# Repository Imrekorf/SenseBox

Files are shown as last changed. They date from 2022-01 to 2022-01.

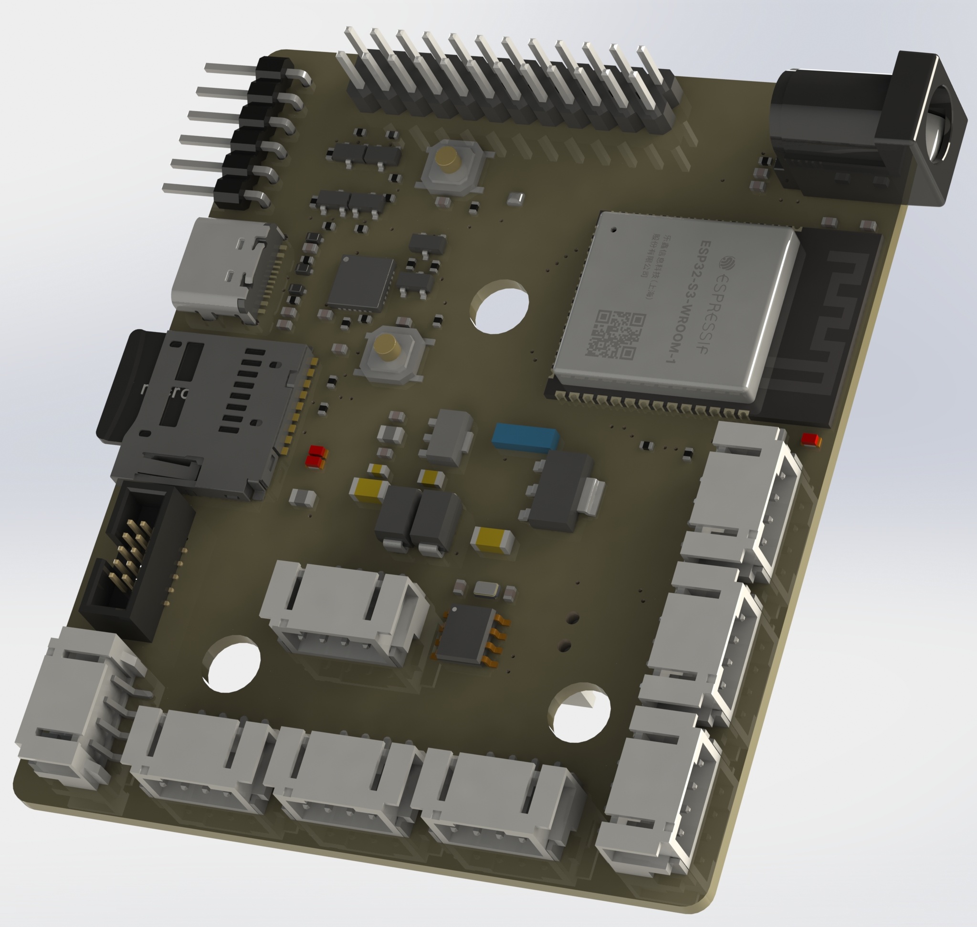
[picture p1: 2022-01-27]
Schematics/Eagle/Models/renderESP32.JPG

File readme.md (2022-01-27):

# Table of contents
- [Table of contents](#table-of-contents)
- [setup guide](#setup-guide)
- [Hardware setup guide](#hardware-setup-guide)
	- [Soldering list](#soldering-list)
	- [Managing the power source](#managing-the-power-source)
	- [Connecting the sensors](#connecting-the-sensors)
		- [Datasheets from the currently used sensors](#datasheets-from-the-currently-used-sensors)
		- [Schematics usage](#schematics-usage)
- [Programming the PCB](#programming-the-pcb)
- [Troubleshooting errors](#troubleshooting-errors)
	- [RTC](#rtc)
	- [SD](#sd)
	- [Sensor initialisation errors](#sensor-initialisation-errors)
- [Correct Installation check](#correct-installation-check)

# setup guide

1. Clone this github repo
2. Generate a MQTTSettings.dat file using the ArduinoConfig-Generator script.
3. Move generated MQTTSettings.dat to SD card's root folder.
4. Power the PCB.

# Hardware setup guide

## Soldering list
1. Solder the DC barreljack
2. Solder the BT1 Battery holder.[^1]
3. Solder the Laser dust sensor connector pins.[^1]
4. Solder the VR5V and VR5V jumpers.

[^1]: Currently the Laser Dust sensor connectors and Battery holder have not yet arrived so that sensor and battery holder can not be connected yet.

## Managing the power source
Depending on the circumstance you might want to power the PCB from the USB connection.<br>
To do this, **first**, you must make sure that VR5V and VR3V3 solder pads are not soldered. This can be identified by seeing 2 small pads on both the solder pads.<br>
Secondly you must solder the USB3V3 and USB5V to provide power to the board from the USB.<br>
If the DC barreljack is used you must **desolder** the USB3V3 and USB5V and then solder the VR3V3 and VR5V.<br>
<br>
To power the RTC you must either solder on the battery holder on the BT1 footprint. Or you can solder a wire from the VR3V3 or USB3V3, whichever is currently providing the 3V3 power, to the 3V3 pad of the Battery holder pads. See the board schematic included in the Schematics folder for more details.<br><br>

## Connecting the sensors
The sensors should be connected to the different JST headers provided on the board. To do this you need male `JST-PH 2.0 4 pin connectors`. 
These can be ordered from [vanallesenmeer.nl](https://www.vanallesenmeer.nl/JST-2.0-PH-4pin-set-recht-met-kabel-30cm) for €0.95.
These cables' other end can then be soldered to the sensors. Currently i2c compatible devices are wired as followed from left to right:
1. SCL : black
2. SDA : red
3. 3v3 : white
4. GND : yellow.

Other sensors' connection diagrams should be taken from the provided schematics.

### Datasheets from the currently used sensors
- [SCD30-datasheet](https://docs.rs-online.com/2d49/0900766b816b6f9d.pdf) & [SCD30-interface descriptor](https://docs.rs-online.com/ba78/0900766b816b6f9c.pdf)
- [Ambimate datasheet](https://docs.rs-online.com/6304/A700000006497831.pdf), [Product specifications](https://www.te.com/commerce/DocumentDelivery/DDEController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), [Application Specifications](https://www.te.com/commerce/DocumentDelivery/DDEController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), [customer drawings](https://eu.mouser.com/datasheet/2/418/7/ENG_CD_2314291_A2-2032749.pdf)
- [TSL2591](https://learn.adafruit.com/adafruit-tsl2591/downloads)
- [AS7262](https://learn.adafruit.com/adafruit-as7262-6-channel-visible-light-sensor/overview)
- [SM-UART-04L](https://www.farnell.com/datasheets/2756490.pdf)
- [MIX8410](https://wiki.seeedstudio.com/Grove-Gas_Sensor-O2-MIX8410/)
- [MAX4466](https://datasheets.maximintegrated.com/en/ds/MAX4465-MAX4469.pdf)
- [PCF8563](https://www.nxp.com/docs/en/data-sheet/PCF8563.pdf)

Any other datasheets needed are included in the EAGLE library. Check the description of the different components to find these datasheets.

### Schematics usage
The .sch and .brd file contain the electrical diagrams and PCB board layout respectively. The pdf contains a quick summary of the .sch file.
The .sch and .brd files can be loaded into the Autocad EAGLE software to make changes and view other information.
The .csv files contain JLCPCB part numbers and placements. These are used to order the right SMD components on the board.

# Programming the PCB
To program the ESP32 on the PCB, provide a power source, either through the USB or the barrel jack depending on the currently soldered connections.
Then load the code into the arduino ide by opening the .ino file. You then need to select the ESP32 dev module as your board in the Tools section.
If this is not already present follow the following [tutorial](https://randomnerdtutorials.com/installing-the-esp32-board-in-arduino-ide-windows-instructions/) to add support for these boards.
Select the correct port in the arduino ide and upload the code.
**important:** when the "connecting ...." prompt comes up, press and hold the RST and BOOT buttons, then release the RST button. if the prompt stops printing `.` or `-`'s then release the BOOT button.

# Troubleshooting errors
The most common errors in the serial output will be that either the RTC, SD or other sensors are not connected. Currently the program does not stop at these errors which could lead to a SYS_RST error message from the ESP32.
## RTC
If the RTC is not working there is either a short circuit on the i2c bus or the RTC does not have power. The RTC is the first module to be initialized in the system for logging purposes, so this has some major consequences when it's not working.

## SD
The most common SD card error is that it is not plugged in. Which can be solved by plugging in the SD card, or replugging the SD card and restarting the system when it was plugged in.
The provided SD card should be flashed with an FAT32 format to make sure the ESP32 can write to it.

## Sensor initialisation errors
If problems arise with the sensors not initializing it is likely due to bad wiring or not being connected at all.

# Correct Installation check
If the installation and connections are all correct you should see the following popping up in the serial monitor after a reset.

```
[14:39:31] [Info]: AmbiMate Firmware version 2.8
[14:39:32] [Info]: AS7262 initialized
[14:39:32] [Info]: SM_UART_4L found and initialized.
[14:39:32] [Info]: SCD30 initialized.
[14:39:32] [Info]: Found a TSL2591 sensor
[14:39:32] [Info]: TSL2591 bootup
------------------------------------
Gain:         25x (Medium)
Timing:       300 ms
------------------------------------

[14:39:33] [Info]: Connecting to WiFi .......
Connencted to wiFi with ip: 192.168.178.53
[14:39:38] [Info]: 
Starting connection to server...
[14:39:38] [Info]: The client SenseBox_test connects to the public mqtt broker
[54:39:40] [Info]: Mqtt broker connected
```

Followed by Info logs containing sensor data.
This data should also be partially tracable to the IoT platform.

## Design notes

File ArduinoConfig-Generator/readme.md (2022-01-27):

# ArduinoConfig-Generator
This script generates a dat file containing encrypted internet connection data.
The script can be expanded on by added variables to the WiFiSettings struct and adding a way to set it in the `getWifiConfig()` function.
If new variables are added, don't forget to also implement a formatting method on the ESP32 code. 
This should be done in the MQTTClient::getSettings() function.

# compiling

compile on an msys2 configured machine by using `make`
otherwise use `make -f MakefileWindows` aslong as you have a preconfigured g++ path.

# installing

After compiling copy the MQTTSettings.dat to the appointed path on the SD card. ( by default the root folder. )
The ESP32 will handle the decrypting.

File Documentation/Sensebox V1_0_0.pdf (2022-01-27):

## Sensebox

Generated by Doxygen 1.9.2

i

1 Module Index | 1
2 Hierarchical Index | 3
3 Class Index | 5
4 File Index | 7
5 Module Documentation | 9
6 Class Documentation | 15

Generated by Doxygen

ii

iii

iv

v

7 File Documentation | 65

vi

Index | 85

# Chapter 1

# Module Index

## 1.1 Modules

Here is a list of all modules:

### 2 Module Index

# Chapter 2

# Hierarchical Index

## 2.1 Class Hierarchy

This inheritance list is sorted roughly, but not completely, alphabetically:

__iW_Module | 15
Logger | 51
__W_AS726X | 19
__W_Ambimate | 17
__W_MAX4466 | 24
__W_MIX8410 | 26
__W_RTC | 28
__W_SCD30 | 30
__W_SD | 37
__W_SM_UART_4L | 43
__W_TSL2591 | | 45
AmbimateData | | 48
ColorSpectrum | | 50
iSingleton | | 51
Logger | 51
__W_AS726X | 19
__W_Ambimate | 17
__W_MAX4466 | 24
__W_MIX8410 | 26
__W_RTC | 28
__W_SCD30 | 30
__W_SD | 37
__W_SM_UART_4L | 43
__W_TSL2591 | | 45
RTC_DATE_TIME | | 57
SBox | | 58
SCD30_DATA | | 61
TSL2591_DATA | | 62

### 4 Hierarchical Index

# Chapter 3

# Class Index

## 3.1 Class List

Here are the classes, structs, unions and interfaces with brief descriptions:

__iW_Module
Interface for a hardware module hardware module should be implemented as a singleton to ensure that there won't be two processes accessing the same hardware at the same time Singleton

__W_Ambimate

__W_AS726X

__W_MAX4466

__W_MIX8410

__W_RTC

__W_SCD30

__W_SD

__W_SM_UART_4L

__W_TSL2591

AmbimateData

ColorSpectrum

iSingleton
Singleton template this doesn't actually implement anything, but this is more for keeping track if
a class is a singleton. Should assure that only one instance of the class can exist at a time | . . | 51
Logger
Logger singleton class. Logger is implemented as a Singleton to prevent two simultaneous logger

RTC_DATE_TIME

SBox

### 6 Class Index

SCD30_DATA

TSL2591_DATA

# Chapter 4

# File Index

## 4.1 File List

Here is a list of all documented files with brief descriptions:

src/Defines/Defines.h

src/Logger/Logger.h

src/Sbox/Sbox.h

src/Wrappers/__W_Module/__iW_Module.h

src/Wrappers/RTC/__W_RTC.h

src/Wrappers/SD/__W_SD.h

src/Wrappers/Sensors/Ambimate/__W_Ambimate.h

src/Wrappers/Sensors/AS7262/__W_AS726X.cpp

src/Wrappers/Sensors/DustSensor/__W_SMUART_4L.h

src/Wrappers/Sensors/MAX4466/__W_MAX4466.h

src/Wrappers/Sensors/MIX8410/__W_MIX8410.h

src/Wrappers/Sensors/SCD30/__W_SCD30.h

src/Wrappers/Sensors/TSL2591/__W_TSL2591.h

src/Wrappers/Singleton/Singleton.h

### 8 File Index

# Chapter 5

# Module Documentation

## 5.1 Global defines

Macros

- #define SenseBox_VERSION "0.0.1"

Version of the Sensebox software A change in the first version indicator is a major version change which might not be compatible with older major versions A change in the second version indicator is a minor version change which should be compatible with other of the same major versions A change in the third version indicator is a tweak version change, this will include mostly small bug fixes

- #define DEBUGLEVEL 3

Used by the source code to indicate what to debug to serial monitor.
- #define LOGLEVEL 3

Used by the source code to indicate what to log to the SD card.

### 5.1.1 Detailed Description

### 5.1.2 Macro Definition Documentation

### 5.1.2.1 DEBUGLEVEL

#define DEBUGLEVEL 3

Used by the source code to indicate what to debug to serial monitor.

Value | Description
0 | Print nothing to serial
1 | Print errors to serial
2 | Print errors and warnings to serial
3 | Print errors, warnings & info to serial
4 | Print errors, Warnings, info & data-dumps to serial

### 10 Module Documentation

### 5.1.2.2 LOGLEVEL

#define LOGLEVEL 3

Used by the source code to indicate what to log to the SD card.

Value | Description
0 | Log nothing
1 | Logs only errors
2 | Logs errors & warnings
3 | Logs errors, warnings & info
4 | Logs errors, warnings, info & data-dumps

## 5.2 Global Enumerations

Enumerations

- enum ERR_Type {
SUCCESS = 0 , READ_SUCCESS = 0 , ALREADY_INITIALIZED = 0 , ERROR = 1 , READ_ERROR = 1 , READ_FAIL = 1 , NOT_INITIALIZED , SD_NOT_INIT , MOD_INIT_ERR , RTC_BEGIN_ERR , SD_BEGIN_ERR , NO_SD_CARD , SD_CARDTYPE_NONE , SD_DIR_OPEN_FAIL , SD_NOT_A_DIR , SD_MKDIR_FAIL , SD_RMDIR_FAIL , SD_FILE_OPEN_FAIL , SD_WRITE_FAIL , SD_APP_FAIL , SD_RENAME_FAIL , SD_RM_FAIL , AMBI_I2C_INIT_ERR , AS726X_BEGIN_ERR , AS726X_DATA_NOT_READY , NO_LDS_SENSOR , SCD30_BEGIN_ERR , TSL_BEGIN_ERR }

List of function return errors.
- enum class LogLevel {
LogLevel::Error , LogLevel::Warning , LogLevel::Info , LogLevel::DataDump ,
LogLevel::__PREV }

Enum values that indicate the log level of the message.
- enum class LogType { LogType::SD = 0b01 , LogType::Serial = 0b10 , LogType::Serial_SD = 0b11 }

Enum values that indicate to which logging device should be logged.

### 5.2.1 Detailed Description

### 5.2.2 Enumeration Type Documentation

### 5.2.2.1 ERR_Type

enum ERR_Type

List of function return errors.

5.2 Global Enumerations | 11

Enumerator

SUCCESS | SUCCESS, No error occured.
READ_SUCCESS | READ_SUCCESS, A read operation was succesfull.
ALREADY_INITIALIZED | ALREADY_INITIALIZED, Module's init function was called multiple times.
ERROR | ERROR, generic error
READ_ERROR | READ_ERROR, A generic read error
READ_FAIL | READ_FAIL, A read operation failed.
NOT_INITIALIZED | NOT_INITIALIZED, Indicates that the module has not been initialized correctly.
SD_NOT_INIT | SD_NOT_INIT, indicates that the SD has not been properly initialized.
MOD_INIT_ERR | MOD_INIT_ERR, indicates that a module was not succesfully initialized.
RTC_BEGIN_ERR | RTC_BEGIN_ERR, indicates that the .begin() method has failed.
SD_BEGIN_ERR | SD_BEGIN_ERR, indicates that the .begin() method has failed.
NO_SD_CARD | NO_SD_CARD, indicates that no SD card was inserted.
SD_CARDTYPE_NONE | SD_CARDTYPE_NONE, indicates that the inserted SD card type is not supported.
SD_DIR_OPEN_FAIL | SD_DIR_OPEN_FAIL, failed to open given directory.
SD_NOT_A_DIR | SD_NOT_A_DIR, given directory does not exist
SD_MKDIR_FAIL | SD_MKDIR_FAIL, failed to create given directory
SD_RMDIR_FAIL | SD_RMDIR_FAIL, failed to remove given directory
SD_FILE_OPEN_FAIL | SD_FILE_OPEN_FAIL, failed to open given file
SD_WRITE_FAIL | SD_WRITE_FAIL, failed to write message to file
SD_APP_FAIL | SD_APP_FAIL, failed to append message to file
SD_RENAME_FAIL | SD_RENAME_FAIL, failed to rename file
SD_RM_FAIL | SD_RM_FAIL, failed to remove file
AMBI_I2C_INIT_ERR | AMBI_I2C_INIT_ERR, Aindicates that an I2C error occured in the init function.
AS726X_BEGIN_ERR | AS726X_BEGIN_ERR, indicates that the .begin() method has failed.
AS726X_DATA_NOT_READY | AS726X_DATA_NOT_READY, indicates that a ready was attempted but data was not yet ready
NO_LDS_SENSOR | NO_LDS_SENSOR, indicates that no LDS sensor was found.
SCD30_BEGIN_ERR | SCD30_BEGIN_ERR, indicates that the .begin() method has failed.
TSL_BEGIN_ERR | TSL_BEGIN_ERR, indicates that the .begin() method has failed.

### 5.2.2.2 LogLevel

enum class LogLevel [strong]

Enum values that indicate the log level of the message.

See also

LogType

Logger::print()

Logger::println()

Logger::write()

### 12 Module Documentation

Enumerator

Error | (0) Error level, This is used for when an error occures that can break the rest of the system.
Warning | (1) Warning level, This is used for when an error occures that does not have a signficiant impact on the system.
Info | (2) Info level, This is used for logging info or debugging info to the SD card.
DataDump | (3) DataDump, This is a special type of logging used for big blocks of data.
__PREV | () __PREV, default value for the logging functions, if this is passed to the function it will use the previous log level.

### 5.2.2.3 LogType

enum class LogType [strong]

Enum values that indicate to which logging device should be logged.

See also

LogLevel

Logger::print()

Logger::println()

Logger::write()

Logger::breakLine()

Logger::dataDumpEnd()

Enumerator

SD | (0) SD card, Flag to only log the passed info to the SD card.
Serial | (1) Serial, Flag to only log the passed info to the Serial.
Serial_SD | (2) Serial_SD, Flag to log to the passed info to both the Serial and SD.

## 5.3 Global structures

Classes

- struct RTC_DATE_TIME

Struct containing the date and time of when the read() function was called.
- struct AmbimateData

struct containing the ambimate data.
- struct ColorSpectrum

Struct containing the read colorspectrum values.
- struct SCD30_DATA

Struct containg the SCD30 Data.
- struct TSL2591_DATA

Struct containing the TSL2591 data.

5.3 Global structures | 13

### 5.3.1 Detailed Description

### 14 Module Documentation

# Chapter 6

# Class Documentation

## 6.1 __iW_Module Class Reference

Interface for a hardware module hardware module should be implemented as a singleton to ensure that there won't be two processes accessing the same hardware at the same time Singleton format: https←-://stackoverflow.com/a/1008289.

#include <__iW_Module.h>

Inheritance diagram for __iW_Module:

### 16 Class Documentation

Public Member Functions

- virtual ERR_Type init ()=0

a standard initialisation method

Protected Member Functions

- virtual bool checkInitialized ()

Checks if the Init function has been called.

Protected Attributes

- bool Initialized = false

The Initialized flag is used to keep track of the state of the Module.

### 6.1.1 Detailed Description

Interface for a hardware module hardware module should be implemented as a singleton to ensure that there won't be two processes accessing the same hardware at the same time Singleton format: https←-://stackoverflow.com/a/1008289.

### 6.1.2 Member Function Documentation

### 6.1.2.1 checkInitialized()

virtual bool __iW_Module::checkInitialized ( ) [inline], [protected], [virtual]

Checks if the Init function has been called.

some sensors will have an initialisation that needs to be completed first. Internally the functions of those sensors should start with a check if the sensor is initialized and if it is not immediatly return.

Returns

true the init function has been called and exited successfully

false the init function has not been called or exited with an error.

6.2 __W_Ambimate Class Reference | 17

### 6.1.2.2 init()

virtual ERR_Type __iW_Module::init ( ) [pure virtual]

a standard initialisation method

Returns

ERR_Type returns 0 on success, 1 on failure

See also

ERR_Type

Implemented in Logger, __W_RTC, __W_SD, __W_Ambimate, __W_AS726X, __W_SM_UART_4L, __W_MAX4466, __W_MIX8410, __W_SCD30, and __W_TSL2591.

The documentation for this class was generated from the following file:

- src/Wrappers/__W_Module/__iW_Module.h

## 6.2 __W_Ambimate Class Reference

Singleton ambimate module.

#include <__W_Ambimate.h>

Inheritance diagram for __W_Ambimate:

Public Member Functions

- __W_Ambimate (__W_Ambimate const &)=delete
- void operator= (__W_Ambimate const &)=delete
- ERR_Type init ()

Initializes the Ambimate object. Should only be called once. This function initializes the Ambimate object. It has a check build in to see if this function has already been called before. If so it will just return 0.
- AmbimateData read ()

Reads the Ambimate sensor's data into the AmbimateData struct. eCO2/VOC sensor is only updated in AmbiMate every 60 seconds.
- uint8_t get_opt_sensors ()

Get the opt sensors flags.

### 18 Class Documentation

Static Public Member Functions

- static __W_Ambimate & getInstance ()

Get the singleton instance of the class This function makes sure that only one instance is created and accessible during runtime.

Additional Inherited Members

### 6.2.1 Detailed Description

Singleton ambimate module.

### 6.2.2 Member Function Documentation

### 6.2.2.1 get_opt_sensors()

uint8_t __W_Ambimate::get_opt_sensors ( )

Get the opt sensors flags.

Returns

uint8_t byte containing the optional sensor flags.

### 6.2.2.2 getInstance()

static __W_Ambimate & __W_Ambimate::getInstance ( ) [inline], [static]

Get the singleton instance of the class This function makes sure that only one instance is created and accessible during runtime.

Returns

__W_Ambimate& the handle to the singleton instance

6.3 __W_AS726X Class Reference | 19

### 6.2.2.3 init()

ERR_Type __W_Ambimate::init ( ) [virtual]

Initializes the Ambimate object. Should only be called once. This function initializes the Ambimate object. It has a check build in to see if this function has already been called before. If so it will just return 0.

Returns

ERR_Type returns SUCCESS on succesfull exit. Else it will return an error code.

See also

ERR_Type

Implements __iW_Module.

### 6.2.2.4 read()

AmbimateData __W_Ambimate::read ( )

Reads the Ambimate sensor's data into the AmbimateData struct. eCO2/VOC sensor is only updated in AmbiMate every 60 seconds.

Returns

AmbimateData the struct containing the read data.

The documentation for this class was generated from the following files:

- src/Wrappers/Sensors/Ambimate/__W_Ambimate.h
- src/Wrappers/Sensors/Ambimate/__W_Ambimate.cpp

## 6.3 __W_AS726X Class Reference

Singleton AS726X module.

#include <__W_AS726X.h>

Inheritance diagram for __W_AS726X:

### 20 Class Documentation

Public Member Functions

- __W_AS726X (__W_AS726X const &)=delete
- void operator= (__W_AS726X const &)=delete
- ERR_Type init ()

Initializes the AS726X object. Should only be called once. This function initializes the AS726X object. It has a check build in to see if this function has already been called before. If so it will just return 0.
- void setDrvLed (bool B)

turn the Drv Led on or off.
- void setDrvCurrent (uint8_t V)

Set the Drv Led current.
- void indicateLED (bool B)

turn the indicate Led on or off.
- void setIndicateCurrent (uint8_t V)

Set the indicate Led current.
- void setGain (uint8_t gain)

Set the Gain value.
- void setIntegrationTime (uint8_t time)

Set the Integration Time.
- void setConversionType (uint8_t type)

Set the Conversion Type.
- void startMeasurement ()

Start a measurement.
- bool checkDataReady ()

Check if the data is ready.
- void getMeasurements (ColorSpectrum ∗CS)

Get the Measurements.
- uint8_t getTemperature ()

Get the Temperature value.

Static Public Member Functions

- static __W_AS726X & getInstance ()

Get the singleton instance of the class This function makes sure that only one instance is created and accessible during runtime.

Additional Inherited Members

### 6.3.1 Detailed Description

Singleton AS726X module.

### 6.3.2 Member Function Documentation

6.3 __W_AS726X Class Reference | 21

### 6.3.2.1 checkDataReady()

bool __W_AS726X::checkDataReady ( )

Check if the data is ready.

Returns

true Data is ready.

false Data is not ready.

### 6.3.2.2 getInstance()

static __W_AS726X & __W_AS726X::getInstance ( ) [inline], [static]

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

Returns

__W_AS726X& the handle to the singleton instance

### 6.3.2.3 getMeasurements()

void __W_AS726X::getMeasurements (

ColorSpectrum ∗ CS )

Get the Measurements.

Parameters

CS The object into which the measurements should be read.

### 6.3.2.4 getTemperature()

uint8_t __W_AS726X::getTemperature ( )

Get the Temperature value.

Returns

uint8_t The read temperature.

### 22 Class Documentation

### 6.3.2.5 indicateLED()

void __W_AS726X::indicateLED (

bool B )

turn the indicate Led on or off.

Parameters

B On or Off.

### 6.3.2.6 init()

ERR_Type __W_AS726X::init ( ) [virtual]

Initializes the AS726X object. Should only be called once. This function initializes the AS726X object. It has a check build in to see if this function has already been called before. If so it will just return 0.

Returns

ERR_Type returns SUCCESS on succesfull exit. Else it will return an error code.

See also

ERR_Type

Implements __iW_Module.

### 6.3.2.7 setConversionType()

void __W_AS726X::setConversionType (

uint8_t type )

Set the Conversion Type.

Parameters

type The conversion Type.

### 6.3.2.8 setDrvCurrent()

void __W_AS726X::setDrvCurrent (

uint8_t V )

6.3 __W_AS726X Class Reference | 23

Set the Drv Led current.

Parameters

V the current value.

### 6.3.2.9 setDrvLed()

void __W_AS726X::setDrvLed (

bool B )

turn the Drv Led on or off.

Parameters

B On or Off.

### 6.3.2.10 setGain()

void __W_AS726X::setGain (

uint8_t gain )

Set the Gain value.

Parameters

gain the gain value.

### 6.3.2.11 setIndicateCurrent()

void __W_AS726X::setIndicateCurrent (

uint8_t V )

Set the indicate Led current.

Parameters

V the current value.

### 24 Class Documentation

### 6.3.2.12 setIntegrationTime()

void __W_AS726X::setIntegrationTime (

uint8_t time )

Set the Integration Time.

Parameters

time the integration time.

The documentation for this class was generated from the following files:

- src/Wrappers/Sensors/AS7262/__W_AS726X.h
- src/Wrappers/Sensors/AS7262/__W_AS726X.cpp

## 6.4 __W_MAX4466 Class Reference

Singleton MAX4466 module.

#include <__W_MAX4466.h>

Inheritance diagram for __W_MAX4466:

Public Member Functions

- __W_MAX4466 (__W_MAX4466 const &)=delete
- void operator= (__W_MAX4466 const &)=delete
- ERR_Type init ()

Initializes the MAX4466 object. Should only be called once. This function initializes the MAX4466 object. It has a check build in to see if this function has already been called before. If so it will just return 0.
- int read ()

Reads the MAX4466 analog value.

Static Public Member Functions

- static __W_MAX4466 & getInstance ()

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

6.4 __W_MAX4466 Class Reference | 25

Additional Inherited Members

### 6.4.1 Detailed Description

Singleton MAX4466 module.

### 6.4.2 Member Function Documentation

### 6.4.2.1 getInstance()

static __W_MAX4466 & __W_MAX4466::getInstance ( ) [inline], [static]

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

Returns

__W_MAX4466& the handle to the singleton instance

### 6.4.2.2 init()

ERR_Type __W_MAX4466::init ( ) [virtual]

Initializes the MAX4466 object. Should only be called once. This function initializes the MAX4466 object. It has a check build in to see if this function has already been called before. If so it will just return 0.

Returns

ERR_Type returns SUCCESS on succesfull exit. Else it will return an error code.

See also

ERR_Type

Implements __iW_Module.

### 26 Class Documentation

### 6.4.2.3 read()

int __W_MAX4466::read ( )

Reads the MAX4466 analog value.

Returns

int The ADC converted value.

The documentation for this class was generated from the following files:

- src/Wrappers/Sensors/MAX4466/__W_MAX4466.h
- src/Wrappers/Sensors/MAX4466/__W_MAX4466.cpp

## 6.5 __W_MIX8410 Class Reference

Singleton MIX8410 module.

#include <__W_MIX8410.h>

Inheritance diagram for __W_MIX8410:

Public Member Functions

- __W_MIX8410 (__W_MIX8410 const &)=delete
- void operator= (__W_MIX8410 const &)=delete
- ERR_Type init ()

Initializes the MIX8410 object. Should only be called once. This function initializes the MIX8410 object. It has a check build in to see if this function has already been called before. If so it will just return 0.
- float readConcentration ()

Converted ADC value into O2 percentage.
- float readO2Vout ()

Reads the ADC value and converts it into a voltage value.

Static Public Member Functions

- static __W_MIX8410 & getInstance ()

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

6.5 __W_MIX8410 Class Reference | 27

Additional Inherited Members

### 6.5.1 Detailed Description

Singleton MIX8410 module.

### 6.5.2 Member Function Documentation

### 6.5.2.1 getInstance()

static __W_MIX8410 & __W_MIX8410::getInstance ( ) [inline], [static]

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

Returns

__W_MIX8410& the handle to the singleton instance

### 6.5.2.2 init()

ERR_Type __W_MIX8410::init ( ) [inline], [virtual]

Initializes the MIX8410 object. Should only be called once. This function initializes the MIX8410 object. It has a check build in to see if this function has already been called before. If so it will just return 0.

Returns

ERR_Type returns SUCCESS on succesfull exit. Else it will return an error code.

See also

ERR_Type

Implements __iW_Module.

### 28 Class Documentation

### 6.5.2.3 readConcentration()

float __W_MIX8410::readConcentration ( )

Converted ADC value into O2 percentage.

Returns

float The Percentage of Oxygen in the air.

### 6.5.2.4 readO2Vout()

float __W_MIX8410::readO2Vout ( )

Reads the ADC value and converts it into a voltage value.

Returns

float The read ADC value.

The documentation for this class was generated from the following files:

- src/Wrappers/Sensors/MIX8410/__W_MIX8410.h
- src/Wrappers/Sensors/MIX8410/__W_MIX8410.cpp

## 6.6 __W_RTC Class Reference

Singleton RTC Module.

#include <__W_RTC.h>

Inheritance diagram for __W_RTC:

Public Member Functions

- __W_RTC (__W_RTC const &)=delete
- void operator= (__W_RTC const &)=delete
- ERR_Type init ()

Initializes the RTC object. Should only be called once. This function initializes the RTC object. It has a check build in to see if this function has already been called before. If so it will just return 0.
- RTC_DATE_TIME read ()

Returns the current date time.
- String stringDateTime ()

Returns a datetime in a string format.
- String stringTime ()

Returns the time in a string format.

6.6 __W_RTC Class Reference | 29

Static Public Member Functions

- static __W_RTC & getInstance ()

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

Additional Inherited Members

### 6.6.1 Detailed Description

Singleton RTC Module.

### 6.6.2 Member Function Documentation

### 6.6.2.1 getInstance()

static __W_RTC & __W_RTC::getInstance ( ) [inline], [static]

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

Returns

__W_RTC& the handle to the singleton instance

### 6.6.2.2 init()

ERR_Type __W_RTC::init ( ) [virtual]

Initializes the RTC object. Should only be called once. This function initializes the RTC object. It has a check build in to see if this function has already been called before. If so it will just return 0.

Returns

ERR_Type returns SUCCESS on succesfull exit. Else it will return an error code.

See also

ERR_Type

Implements __iW_Module.

### 30 Class Documentation

### 6.6.2.3 read()

RTC_DATE_TIME __W_RTC::read ( )

Returns the current date time.

Returns

the current date time in a RTC_DATE_TIME struct.

### 6.6.2.4 stringDateTime()

String __W_RTC::stringDateTime ( )

Returns a datetime in a string format.

Returns

a datetime in a YYYY-MM-DD_hh.mm.ss format.

### 6.6.2.5 stringTime()

String __W_RTC::stringTime ( )

Returns the time in a string format.

Returns

a time string in a hh.mm.ss format.

The documentation for this class was generated from the following files:

- src/Wrappers/RTC/__W_RTC.h
- src/Wrappers/RTC/__W_RTC.cpp

## 6.7 __W_SCD30 Class Reference

Singleton SCD30 module.

#include <__W_SCD30.h>

Inheritance diagram for __W_SCD30:

6.7 __W_SCD30 Class Reference | 31

Public Member Functions

- __W_SCD30 (__W_SCD30 const &)=delete
- void operator= (__W_SCD30 const &)=delete
- SCD30_DATA read ()

Reads the SCD30 sensor.
- ERR_Type init (bool autoCalibrate)

Init function if autoCalibrate is set to true, this will activate the sensors autocalibrate feature. Please see section 1.3.6 of the SCD30 datasheet: "When activated for the first time a period of minimum 7 days is needed so that the algorithm can find its initial parameter set for ASC. The sensor has to be exposed to fresh air for at least 1 hour every day. Also during that period, the sensor may not be disconnected from the power supply, otherwise the procedure to find calibration parameters is aborted and has to be restarted from the beginning. The successfully calculated parameters are stored in non-volatile memory of the SCD30 having the effect that after a restart the previously found parameters for ASC are still present. ".
- ERR_Type init ()

Initializes the SCD30 object. Should only be called once. This function initializes the SCD30 object. It has a check build in to see if this function has already been called before. If so it will just return 0.
- bool dataAvailable ()

Checks if the data is available.
- uint16_t getCO2 ()

Returns the read CO2 ppm value.
- float getTemperature ()

Get the Temperature value.
- float getHumidity ()

Get the Humidity level.
- void setMeasurementsInterval (uint16_t seconds)

Set the Measurements Interval. Change number of seconds between measurements: 2 to 1800 (30 minutes), stored in non-volatile memory of SCD30.
- bool getMeasurementsInterval (uint16_t &seconds)

Get the Measurements Interval.
- void setAltitudeCompensation (uint16_t altitude)

Set the Altitude Compensation Set altitude of the sensor in m, stored in non-volatile memory of SCD30.
- bool getAltitudeCompensation (uint16_t &altitude)

Get the Altitude Compensation object.
- void setAmbientPressure (uint16_t Pressure)

Set the Ambient Pressure. Current ambient pressure in mBar: 700 to 1200, will overwrite altitude compensation.
- void setTemperatureOffset (float offset)

Set the Temperature Offset Optionally we can set temperature offset to °C, stored in non-volatile memory of SCD30.
- bool getTemperatureOffset (float &offset)

Get the Temperature Offset.
- bool getAutoSelfCalibration ()

Get the Auto Self Calibration value.
- bool getForcedRecalibration (uint16_t &settingVal)

Get the Forced Recalibration value.
- bool getFirmwareVersion (uint16_t &settingVal)

Get the Firmware Version.

Static Public Member Functions

- static __W_SCD30 & getInstance ()

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

### 32 Class Documentation

Additional Inherited Members

### 6.7.1 Detailed Description

Singleton SCD30 module.

### 6.7.2 Member Function Documentation

### 6.7.2.1 dataAvailable()

bool __W_SCD30::dataAvailable ( )

Checks if the data is available.

Returns

true Data is ready.

false Data is not ready.

### 6.7.2.2 getAltitudeCompensation()

bool __W_SCD30::getAltitudeCompensation (

uint16_t & altitude )

Get the Altitude Compensation object.

Parameters

altitude object into which the value should be read.

Returns

true get successfull.

false get failure.

### 6.7.2.3 getAutoSelfCalibration()

bool __W_SCD30::getAutoSelfCalibration ( )

Get the Auto Self Calibration value.

6.7 __W_SCD30 Class Reference | 33

Returns

true autoselfcalibration is on.

false autoselfcalibration is off.

### 6.7.2.4 getCO2()

uint16_t __W_SCD30::getCO2 ( )

Returns the read CO2 ppm value.

Returns

uint16_t the CO2 in ppm.

### 6.7.2.5 getFirmwareVersion()

bool __W_SCD30::getFirmwareVersion (

uint16_t & settingVal )

Get the Firmware Version.

Parameters

settingVal object into which the value should be read.

Returns

true get successfull.

false get failure.

### 6.7.2.6 getForcedRecalibration()

bool __W_SCD30::getForcedRecalibration (

uint16_t & settingVal )

Get the Forced Recalibration value.

Parameters

settingVal object into which the value should be read.

### 34 Class Documentation

Returns

true get successfull.

false get failure.

### 6.7.2.7 getHumidity()

float __W_SCD30::getHumidity ( )

Get the Humidity level.

Returns

float The Humidity level.

### 6.7.2.8 getInstance()

static __W_SCD30 & __W_SCD30::getInstance ( ) [inline], [static]

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

Returns

__W_SCD30& the handle to the singleton instance

### 6.7.2.9 getMeasurementsInterval()

bool __W_SCD30::getMeasurementsInterval (

uint16_t & seconds )

Get the Measurements Interval.

Parameters

seconds object into which the value should be read.

Returns

true get successfull.

false get failure.

6.7 __W_SCD30 Class Reference | 35

### 6.7.2.10 getTemperature()

float __W_SCD30::getTemperature ( )

Get the Temperature value.

Returns

float The temperature.

### 6.7.2.11 getTemperatureOffset()

bool __W_SCD30::getTemperatureOffset (

float & offset )

Get the Temperature Offset.

Parameters

offset object into which the value should be read.

Returns

true get successfull.

false get failure.

### 6.7.2.12 init() [1/2]

ERR_Type __W_SCD30::init ( ) [virtual]

Initializes the SCD30 object. Should only be called once. This function initializes the SCD30 object. It has a check build in to see if this function has already been called before. If so it will just return 0.

Returns

ERR_Type returns SUCCESS on succesfull exit. Else it will return an error code.

See also

ERR_Type

Implements __iW_Module.

### 36 Class Documentation

### 6.7.2.13 init() [2/2]

ERR_Type __W_SCD30::init (

bool autoCalibrate )

Init function if autoCalibrate is set to true, this will activate the sensors autocalibrate feature. Please see section 1.3.6 of the SCD30 datasheet: "When activated for the first time a period of minimum 7 days is needed so that the algorithm can find its initial parameter set for ASC. The sensor has to be exposed to fresh air for at least 1 hour every day. Also during that period, the sensor may not be disconnected from the power supply, otherwise the procedure to find calibration parameters is aborted and has to be restarted from the beginning. The successfully calculated parameters are stored in non-volatile memory of the SCD30 having the effect that after a restart the previously found parameters for ASC are still present. ".

Parameters

autoCalibrate turns on auto calibrate.

Returns

ERR_Type returns SUCCESS on succesfull exit. Else it will return an error code

### 6.7.2.14 read()

SCD30_DATA __W_SCD30::read ( )

Reads the SCD30 sensor.

Returns

SCD30_DATA Struct containing the read SCD30 Data.

### 6.7.2.15 setAltitudeCompensation()

void __W_SCD30::setAltitudeCompensation (

uint16_t altitude )

Set the Altitude Compensation Set altitude of the sensor in m, stored in non-volatile memory of SCD30.

Parameters

altitude Altitude of the sensor in m.

6.8 __W_SD Class Reference | 37

### 6.7.2.16 setAmbientPressure()

void __W_SCD30::setAmbientPressure (

uint16_t Pressure )

Set the Ambient Pressure. Current ambient pressure in mBar: 700 to 1200, will overwrite altitude compensation.

Parameters

Pressure Current ambient pressure in mBar: 700 to 1200

### 6.7.2.17 setMeasurementsInterval()

void __W_SCD30::setMeasurementsInterval (

uint16_t seconds )

Set the Measurements Interval. Change number of seconds between measurements: 2 to 1800 (30 minutes), stored in non-volatile memory of SCD30.

Parameters

seconds

### 6.7.2.18 setTemperatureOffset()

void __W_SCD30::setTemperatureOffset (

float offset )

Set the Temperature Offset Optionally we can set temperature offset to °C, stored in non-volatile memory of SCD30.

Parameters

offset temperature offset.

The documentation for this class was generated from the following files:

- src/Wrappers/Sensors/SCD30/__W_SCD30.h
- src/Wrappers/Sensors/SCD30/__W_SCD30.cpp

## 6.8 __W_SD Class Reference

Singleton SD module.

### 38 Class Documentation

#include <__W_SD.h>

Inheritance diagram for __W_SD:

Public Member Functions

- __W_SD (__W_SD const &)=delete
- void operator= (__W_SD const &)=delete
- ERR_Type init ()

Initializes the SD object. Should only be called once. This function initializes the SD object. It has a check build in to see if this function has already been called before. If so it will just return 0.
- ERR_Type listDir (const char ∗dirname, uint8_t levels)

lists the directories in given path.
- ERR_Type createDir (const char ∗path)

Create a directory at the given path. /path/to/dir will create directory 'dir' in the folder 'to'.
- ERR_Type removeDir (const char ∗path)

Removes the directory at the given path.
- ERR_Type readFile (const char ∗path, char ∗buffer)

Reads the file at the given path into the passed buffer.
- ERR_Type writeFile (const char ∗path, const char ∗message)

rewrites the message to the given file.
- ERR_Type appendFile (const char ∗path, const char ∗message)

Adds the message at the end of the file.
- ERR_Type renameFile (const char ∗path1, const char ∗path2)

renames the file to the given name. e.g. "/path/to/file" "/path/to/file2" rewrites "file" to "file2".
- ERR_Type deleteFile (const char ∗path)

deletes the file at the given path.
- ERR_Type testFileIO (const char ∗path)

tests the IO functionality of the SDcard.

Static Public Member Functions

- static __W_SD & getInstance ()

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

Additional Inherited Members

### 6.8.1 Detailed Description

Singleton SD module.

6.8 __W_SD Class Reference | 39

### 6.8.2 Member Function Documentation

### 6.8.2.1 appendFile()

ERR_Type __W_SD::appendFile (

const char ∗ path,

const char ∗ message )

Adds the message at the end of the file.

Parameters

path | the path to the file.
message | the message to be added to the file.

Returns

ERR_Type returns SUCCESS on succesfull exit. Else it will return an error code.

See also

ERR_Type

### 6.8.2.2 createDir()

ERR_Type __W_SD::createDir (

const char ∗ path )

Create a directory at the given path. /path/to/dir will create directory 'dir' in the folder 'to'.

Parameters

path the path to the directory.

Returns

ERR_Type returns SUCCESS on succesfull exit. Else it will return an error code.

See also

ERR_Type

### 40 Class Documentation

### 6.8.2.3 deleteFile()

ERR_Type __W_SD::deleteFile (

const char ∗ path )

deletes the file at the given path.

Parameters

path path to the file.

Returns

ERR_Type returns SUCCESS on succesfull exit. Else it will return an error code.

See also

ERR_Type

### 6.8.2.4 getInstance()

static __W_SD & __W_SD::getInstance ( ) [inline], [static]

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

Returns

__W_SD& the handle to the singleton instance

### 6.8.2.5 init()

ERR_Type __W_SD::init ( ) [virtual]

Initializes the SD object. Should only be called once. This function initializes the SD object. It has a check build in to see if this function has already been called before. If so it will just return 0.

Returns

ERR_Type returns SUCCESS on succesfull exit. Else it will return an error code.

See also

ERR_Type

Implements __iW_Module.

### 6.8.2.6 listDir()

ERR_Type __W_SD::listDir (

const char ∗ dirname,

uint8_t levels )

lists the directories in given path.

6.8 __W_SD Class Reference | 41

Parameters

dirname | the path to the directory.
levels | the depth of the tree search.

Returns

ERR_Type returns SUCCESS on succesfull exit. Else it will return an error code.

See also

ERR_Type

### 6.8.2.7 readFile()

ERR_Type __W_SD::readFile (

const char ∗ path,

char ∗ buffer )

Reads the file at the given path into the passed buffer.

Parameters

path | the path to the file.
buffer | the buffer that is read into.

Returns

ERR_Type returns SUCCESS on succesfull exit. Else it will return an error code.

See also

ERR_Type

### 6.8.2.8 removeDir()

ERR_Type __W_SD::removeDir (

const char ∗ path )

Removes the directory at the given path.

Parameters

path the path to the directory.

### 42 Class Documentation

Returns

ERR_Type returns SUCCESS on succesfull exit. Else it will return an error code.

See also

ERR_Type

### 6.8.2.9 renameFile()

ERR_Type __W_SD::renameFile (

const char ∗ path1,

const char ∗ path2 )

renames the file to the given name. e.g. "/path/to/file" "/path/to/file2" rewrites "file" to "file2".

Parameters

path1 | the original path to the file.
path2 | the new path to the file.

Returns

ERR_Type returns SUCCESS on succesfull exit. Else it will return an error code.

See also

ERR_Type

### 6.8.2.10 testFileIO()

ERR_Type __W_SD::testFileIO (

const char ∗ path )

tests the IO functionality of the SDcard.

Parameters

path to a file to test.

Returns

ERR_Type returns SUCCESS on succesfull exit. Else it will return an error code.

6.9 __W_SM_UART_4L Class Reference | 43

See also

ERR_Type

### 6.8.2.11 writeFile()

ERR_Type __W_SD::writeFile (

const char ∗ path,

const char ∗ message )

rewrites the message to the given file.

Parameters

path | the path to the file.
message | the message to be written to the file.

Returns

ERR_Type returns SUCCESS on succesfull exit. Else it will return an error code.

See also

ERR_Type

The documentation for this class was generated from the following files:

- src/Wrappers/SD/__W_SD.h
- src/Wrappers/SD/__W_SD.cpp

## 6.9 __W_SM_UART_4L Class Reference

Singleton LDS module.

#include <__W_SMUART_4L.h>

Inheritance diagram for __W_SM_UART_4L:

### 44 Class Documentation

Public Member Functions

- __W_SM_UART_4L (__W_SM_UART_4L const &)=delete
- void operator= (__W_SM_UART_4L const &)=delete
- ERR_Type init ()

Initializes the LDS object. Should only be called once. This function initializes the LDS object. It has a check build in to see if this function has already been called before. If so it will just return 0.
- ERR_Type read (PM25_AQI_Data &data)

Reads the LDS sensor data into the data object.

Static Public Member Functions

- static __W_SM_UART_4L & getInstance ()

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

Additional Inherited Members

### 6.9.1 Detailed Description

Singleton LDS module.

### 6.9.2 Member Function Documentation

### 6.9.2.1 getInstance()

static __W_SM_UART_4L & __W_SM_UART_4L::getInstance ( ) [inline], [static]

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

Returns

__W_SM_UART_4L& the handle to the singleton instance

### 6.9.2.2 init()

ERR_Type __W_SM_UART_4L::init ( ) [virtual]

Initializes the LDS object. Should only be called once. This function initializes the LDS object. It has a check build in to see if this function has already been called before. If so it will just return 0.

Returns

ERR_Type returns SUCCESS on succesfull exit. Else it will return an error code.

See also

ERR_Type

Implements __iW_Module.

6.10 __W_TSL2591 Class Reference | 45

### 6.9.2.3 read()

ERR_Type __W_SM_UART_4L::read (

PM25_AQI_Data & data )

Reads the LDS sensor data into the data object.

Parameters

data The PM25_AQI_Data object into which the data should be read.

Returns

ERR_Type returns SUCCESS on succesfull exit. Else it will return an error code.

See also

ERR_Type

The documentation for this class was generated from the following files:

- src/Wrappers/Sensors/DustSensor/__W_SMUART_4L.h
- src/Wrappers/Sensors/DustSensor/__W_SMUART_4L.cpp

## 6.10 __W_TSL2591 Class Reference

Singleton TSL2591 module.

#include <__W_TSL2591.h>

Inheritance diagram for __W_TSL2591:

Public Member Functions

- __W_TSL2591 (__W_TSL2591 const &)=delete
- void operator= (__W_TSL2591 const &)=delete
- ERR_Type init ()

Initializes the TSL2591 object. Should only be called once. This function initializes the TSL2591 object. It has a check build in to see if this function has already been called before. If so it will just return 0.
- void displaySensorDetails ()

Displays the sensor details to the SD card and Serial.
- uint16_t getLuminosity (uint8_t spectrum=TSL2591_VISIBLE)

Get the Luminosity value.
- TSL2591_DATA getFullLuminosity ()

Read the full luminosity.
- float getLux (uint16_t full, uint16_t ir)

Calculates the visible Lux based on the two light sensors.

### 46 Class Documentation

Static Public Member Functions

- static __W_TSL2591 & getInstance ()

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

Additional Inherited Members

### 6.10.1 Detailed Description

Singleton TSL2591 module.

### 6.10.2 Member Function Documentation

### 6.10.2.1 getFullLuminosity()

TSL2591_DATA __W_TSL2591::getFullLuminosity ( )

Read the full luminosity.

Returns

TSL2591_DATA Struct containing all luminosity data.

### 6.10.2.2 getInstance()

static __W_TSL2591 & __W_TSL2591::getInstance ( ) [inline], [static]

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

Returns

__W_TSL2591& the handle to the singleton instance

### 6.10.2.3 getLuminosity()

uint16_t __W_TSL2591::getLuminosity (

uint8_t spectrum = TSL2591_VISIBLE )

Get the Luminosity value.

6.10 __W_TSL2591 Class Reference | 47

Parameters

spectrum Spectrum to be read. other values are: TSL2591_FULLSPECTRUM or TSL2591_INFRARED.

Returns

uint16_t raw 16-bit ADC value

### 6.10.2.4 getLux()

float __W_TSL2591::getLux (

uint16_t full,

uint16_t ir )

Calculates the visible Lux based on the two light sensors.

Parameters

full | Data from channel 0 (IR+Visible)
ir | Data from channel 1 (IR)

Returns

Lux, based on AMS coefficients (or < 0 if overflow)

### 6.10.2.5 init()

ERR_Type __W_TSL2591::init ( ) [virtual]

Initializes the TSL2591 object. Should only be called once. This function initializes the TSL2591 object. It has a check build in to see if this function has already been called before. If so it will just return 0.

Returns

ERR_Type returns SUCCESS on succesfull exit. Else it will return an error code.

See also

ERR_Type

Implements __iW_Module.

The documentation for this class was generated from the following files:

- src/Wrappers/Sensors/TSL2591/__W_TSL2591.h
- src/Wrappers/Sensors/TSL2591/__W_TSL2591.cpp

### 48 Class Documentation

## 6.11 AmbimateData Struct Reference

struct containing the ambimate data.

#include <__W_Ambimate.h>

Public Attributes

•

union {
uint8_t status
struct {
uint8_t MOT_EVENT: 1
uint8_t AUD_EVENT: 1
uint8_t __pad0__: 5
uint8_t PIR_EVENT: 1
}
};
- float temperatureC
- float Humidity
- float batVolts
- uint16_t light
- uint16_t audio
- uint16_t eco2_ppm
- uint16_t voc_ppm

### 6.11.1 Detailed Description

struct containing the ambimate data.

### 6.11.2 Member Data Documentation

### 6.11.2.1 AUD_EVENT

uint8_t AmbimateData::AUD_EVENT

True when an Audio event has occured.

### 6.11.2.2 audio

uint16_t AmbimateData::audio

Audio level.

6.11 AmbimateData Struct Reference | 49

### 6.11.2.3 batVolts

float AmbimateData::batVolts

Battery voltage.

### 6.11.2.4 eco2_ppm

uint16_t AmbimateData::eco2_ppm

equivalent CO2 ppm.

### 6.11.2.5 Humidity

float AmbimateData::Humidity

Humidity.

### 6.11.2.6 light

uint16_t AmbimateData::light

Light level.

### 6.11.2.7 MOT_EVENT

uint8_t AmbimateData::MOT_EVENT

True when an motion event has occured.

### 6.11.2.8 PIR_EVENT

uint8_t AmbimateData::PIR_EVENT

True when a PIR event has occured.

### 6.11.2.9 status

uint8_t AmbimateData::status

the status full byte.

### 6.11.2.10 temperatureC

float AmbimateData::temperatureC

Temperature in C.

### 50 Class Documentation

### 6.11.2.11 voc_ppm

uint16_t AmbimateData::voc_ppm

VOC ppm.

The documentation for this struct was generated from the following file:

- src/Wrappers/Sensors/Ambimate/__W_Ambimate.h

## 6.12 ColorSpectrum Struct Reference

Struct containing the read colorspectrum values.

#include <__W_AS726X.h>

Public Attributes

- float Violet

Measured violet color spectrum value.
- float Blue

Measured blue color spectrum value.
- float Green

Measured green color spectrum value.
- float Yellow

Measured yellow color spectrum value.
- float Orange

Measured orange color spectrum value.
- float Red

Measured red color spectrum value.

### 6.12.1 Detailed Description

Struct containing the read colorspectrum values.

The documentation for this struct was generated from the following file:

- src/Wrappers/Sensors/AS7262/__W_AS726X.h

6.13 iSingleton Class Reference | 51

## 6.13 iSingleton Class Reference

Singleton template this doesn't actually implement anything, but this is more for keeping track if a class is a singleton. Should assure that only one instance of the class can exist at a time.

#include <Singleton.h>

Inheritance diagram for iSingleton:

### 6.13.1 Detailed Description

Singleton template this doesn't actually implement anything, but this is more for keeping track if a class is a singleton. Should assure that only one instance of the class can exist at a time.

The documentation for this class was generated from the following file:

- src/Wrappers/Singleton/Singleton.h

## 6.14 Logger Class Reference

Logger singleton class. Logger is implemented as a Singleton to prevent two simultaneous logger instances from accessing the serial or sd.

#include <Logger.h>

### 52 Class Documentation

Inheritance diagram for Logger:

Public Member Functions

- Logger (Logger const &)=delete
- void operator= (Logger const &)=delete
- ERR_Type init ()

Initializes the Logger object. Should only be called once. This function initializes the Logger object. It has a check build in to see if this function has already been called before. If so it will just return 0.

- template<typename T >
void print (T value, LogLevel LL=LogLevel::__PREV, LogType LT=LogType::Serial_SD)

Prints the given value to the specified output with the given loglevel. To end the log entry call Logger::println().

- template<typename T >
void println (T value, LogLevel LL=LogLevel::__PREV, LogType LT=LogType::Serial_SD)

Prints the given value to the specified output with the given loglevel and ends the line. Call this function when a log entry ends. If you need multiple prints in the same log entry use Logger::print().
- void print (char ∗s, LogLevel LL=LogLevel::__PREV, LogType LT=LogType::Serial_SD)

Prints the given value to the specified output with the given loglevel. To end the log entry call Logger::println().
- void println (char ∗s, LogLevel LL=LogLevel::__PREV, LogType LT=LogType::Serial_SD)

Prints the given value to the specified output with the given loglevel and ends the line. Call this function when a log entry ends. If you need multiple prints in the same log entry use Logger::print().
- void write (char s, LogLevel LL=LogLevel::__PREV, LogType LT=LogType::Serial_SD)

writes the given character to the specified output with the given loglevel. Use this with loglevel DataDump and Logger::dataDumpEnd(). To end the log entry call Logger::println().
- void breakLine (LogType LT)

adds a linebreak to a log entry without ending it.
- void dataDumpEnd (LogType LT)

End the started datadump entry.

Static Public Member Functions

- static Logger & getInstance ()

Get the Instance of the Logger object. This function makes sure that only one instance is created and accessible during runtime.

Additional Inherited Members

### 6.14.1 Detailed Description

Logger singleton class. Logger is implemented as a Singleton to prevent two simultaneous logger instances from accessing the serial or sd.

6.14 Logger Class Reference | 53

### 6.14.2 Member Function Documentation

### 6.14.2.1 breakLine()

void Logger::breakLine (

LogType LT )

adds a linebreak to a log entry without ending it.

Parameters

LT The Loglevel.

### 6.14.2.2 dataDumpEnd()

void Logger::dataDumpEnd (

LogType LT )

End the started datadump entry.

Parameters

LT The Loglevel.

### 6.14.2.3 getInstance()

static Logger & Logger::getInstance ( ) [inline], [static]

Get the Instance of the Logger object. This function makes sure that only one instance is created and accessible during runtime.

Returns

Logger& The singleton instance of the object.

### 54 Class Documentation

### 6.14.2.4 init()

ERR_Type Logger::init ( ) [virtual]

Initializes the Logger object. Should only be called once. This function initializes the Logger object. It has a check build in to see if this function has already been called before. If so it will just return 0.

Returns

ERR_Type returns SUCCESS on succesfull exit. Else it will return an error code.

See also

ERR_Type

Implements __iW_Module.

### 6.14.2.5 print() [1/2]

void Logger::print (

char ∗ s,

LogLevel LL = LogLevel::__PREV,

LogType LT = LogType::Serial_SD )

Prints the given value to the specified output with the given loglevel. To end the log entry call Logger::println().

Template Parameters

T the datatype of the passed value. Should be convertable to a string.

Parameters

s | the string to be printed.
LL | the log level.
LT | the output to log to.

See also

Logger::println()

Logger::breakLine()

### 6.14.2.6 print() [2/2]

template<typename T >

void Logger::print (

6.14 Logger Class Reference | 55

T value,

LogLevel LL = LogLevel::__PREV,

LogType LT = LogType::Serial_SD ) [inline]

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

Template Parameters

T the datatype of the passed value. Should be convertable to a string.

Parameters

value | the value to be printed.
LL | the log level.
LT | the output to log to.

See also

Logger::println()

Logger::breakLine()

### 6.14.2.7 println() [1/2]

void Logger::println (

char ∗ s,

LogLevel LL = LogLevel::__PREV,

LogType LT = LogType::Serial_SD )

Prints the given value to the specified output with the given loglevel and ends the line. Call this function when a log entry ends. If you need multiple prints in the same log entry use Logger::print().

Template Parameters

T the datatype of the passed value. Should be convertable to a string.

Parameters

s | the value to be printed.
LL | the log level.
LT | the output to log to.

See also

Logger::print()

Logger::breakLine()

### 56 Class Documentation

### 6.14.2.8 println() [2/2]

template<typename T >

void Logger::println (

T value,

LogLevel LL = LogLevel::__PREV,

LogType LT = LogType::Serial_SD ) [inline]

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

Template Parameters

T the datatype of the passed value. Should be convertable to a string.

Parameters

value | the value to be printed.
LL | the log level.
LT | the output to log to.

See also

Logger::print()

Logger::breakLine()

### 6.14.2.9 write()

void Logger::write (

char s,

LogLevel LL = LogLevel::__PREV,

LogType LT = LogType::Serial_SD )

writes the given character to the specified output with the given loglevel. Use this with loglevel DataDump and Logger::dataDumpEnd(). To end the log entry call Logger::println().

Template Parameters

T the datatype of the passed value. Should be convertable to a string.

Parameters

s | the value to be printed.
LL | the log level.
LT | the output to log to.

6.15 RTC_DATE_TIME Struct Reference | 57

See also

Logger::print()

Logger::println()

Logger::breakLine()

Logger::dataDumpEnd()

The documentation for this class was generated from the following files:

- src/Logger/Logger.h
- src/Logger/Logger.cpp

## 6.15 RTC_DATE_TIME Struct Reference

Struct containing the date and time of when the read() function was called.

#include <__W_RTC.h>

Public Attributes

- uint8_t Day
- uint8_t Month
- uint16_t Year
- uint8_t Hour
- uint8_t Minute
- uint8_t Second

### 6.15.1 Detailed Description

Struct containing the date and time of when the read() function was called.

### 6.15.2 Member Data Documentation

### 6.15.2.1 Day

uint8_t RTC_DATE_TIME::Day

Current Day.

### 6.15.2.2 Hour

uint8_t RTC_DATE_TIME::Hour

Current Hour.

### 58 Class Documentation

### 6.15.2.3 Minute

uint8_t RTC_DATE_TIME::Minute

Current Minute.

### 6.15.2.4 Month

uint8_t RTC_DATE_TIME::Month

Current Month.

### 6.15.2.5 Second

uint8_t RTC_DATE_TIME::Second

Current Second.

### 6.15.2.6 Year

uint16_t RTC_DATE_TIME::Year

Current Year.

The documentation for this struct was generated from the following file:

- src/Wrappers/RTC/__W_RTC.h

## 6.16 SBox Class Reference

SBox class containing handles to every sensor on the PCB.

#include <Sbox.h>

Public Member Functions

- ERR_Type init ()

Initializes the SBox object. Should only be called once. This function initializes the SBox object. It has a check build in to see if this function has already been called before. If so it will just return 0.
- RTC_DATE_TIME getTime ()

Get the a date_time struct.
- AmbimateData getAmbimateData ()

Get the Ambimate Data.
- ERR_Type getColorSpectrum (ColorSpectrum &CS)

Get the Color Spectrum data.
- ERR_Type getLDSData (PM25_AQI_Data &Buffer)

Get the Laser Dust Sensor data.
- int getMax4466 ()

Get the Max4466 data.
- float getO2 ()

Get the O2 value.
- SCD30_DATA getSCD30Data ()

Get the SCD30 data.
- TSL2591_DATA getTSL2591Data ()

Get the TSL2591 data.

6.16 SBox Class Reference | 59

### 6.16.1 Detailed Description

SBox class containing handles to every sensor on the PCB.

### 6.16.2 Member Function Documentation

### 6.16.2.1 getAmbimateData()

AmbimateData SBox::getAmbimateData ( )

Get the Ambimate Data.

Returns

AmbimateData struct containing the read ambimate data.

### 6.16.2.2 getColorSpectrum()

ERR_Type SBox::getColorSpectrum (

ColorSpectrum & CS )

Get the Color Spectrum data.

Parameters

CS ColorSpectrum struct buffer.

Returns

ERR_Type returns SUCCESS on succesfull exit. Else it will return an error code.

See also

ERR_Type

### 6.16.2.3 getLDSData()

ERR_Type SBox::getLDSData (

PM25_AQI_Data & Buffer )

Get the Laser Dust Sensor data.

### 60 Class Documentation

Parameters

Buffer PM25_AQI_Data struct buffer.

Returns

ERR_Type returns SUCCESS on succesfull exit. Else it will return an error code.

See also

ERR_Type

### 6.16.2.4 getMax4466()

int SBox::getMax4466 ( )

Get the Max4466 data.

Returns

int ADC value of the Max4466 data.

### 6.16.2.5 getO2()

float SBox::getO2 ( )

Get the O2 value.

Returns

float the read O2 value.

### 6.16.2.6 getSCD30Data()

SCD30_DATA SBox::getSCD30Data ( )

Get the SCD30 data.

Returns

SCD30_DATA struct containing the read SCD30 data.

6.17 SCD30_DATA Struct Reference | 61

### 6.16.2.7 getTime()

RTC_DATE_TIME SBox::getTime ( )

Get the a date_time struct.

Returns

RTC_DATE_TIME struct containing current date and time.

### 6.16.2.8 getTSL2591Data()

TSL2591_DATA SBox::getTSL2591Data ( )

Get the TSL2591 data.

Returns

TSL2591_DATA struct containing the TSL2591 data.

### 6.16.2.9 init()

ERR_Type SBox::init ( )

Initializes the SBox object. Should only be called once. This function initializes the SBox object. It has a check build in to see if this function has already been called before. If so it will just return 0.

Returns

ERR_Type returns SUCCESS on succesfull exit. Else it will return an error code.

See also

ERR_Type

The documentation for this class was generated from the following files:

- src/Sbox/Sbox.h
- src/Sbox/Sbox.cpp

## 6.17 SCD30_DATA Struct Reference

Struct containg the SCD30 Data.

#include <__W_SCD30.h>

### 62 Class Documentation

Public Attributes

- uint16_t CO2
- float Temperature
- float Humidity

### 6.17.1 Detailed Description

Struct containg the SCD30 Data.

### 6.17.2 Member Data Documentation

### 6.17.2.1 CO2

uint16_t SCD30_DATA::CO2

CO2 ppm value

### 6.17.2.2 Humidity

float SCD30_DATA::Humidity

Humidity value

### 6.17.2.3 Temperature

float SCD30_DATA::Temperature

Temperature value

The documentation for this struct was generated from the following file:

- src/Wrappers/Sensors/SCD30/__W_SCD30.h

## 6.18 TSL2591_DATA Struct Reference

Struct containing the TSL2591 data.

#include <__W_TSL2591.h>

6.18 TSL2591_DATA Struct Reference | 63

Public Attributes

- uint16_t visible

Lux values of visible spectrum range.
- uint16_t ir

Lux values of infra red spectrum range.
- uint16_t full

Lux values of full spectrum range.

### 6.18.1 Detailed Description

Struct containing the TSL2591 data.

The documentation for this struct was generated from the following file:

- src/Wrappers/Sensors/TSL2591/__W_TSL2591.h

### 64 Class Documentation

# Chapter 7

# File Documentation

## 7.1 src/Defines/Defines.h File Reference

Defines file used for global precompile settings.

Macros

- #define SenseBox_VERSION "0.0.1"

Version of the Sensebox software A change in the first version indicator is a major version change which might not be compatible with older major versions A change in the second version indicator is a minor version change which should be compatible with other of the same major versions A change in the third version indicator is a tweak version change, this will include mostly small bug fixes

- #define DEBUGLEVEL 3

Used by the source code to indicate what to debug to serial monitor.
- #define LOGLEVEL 3

Used by the source code to indicate what to log to the SD card.

Enumerations

- enum ERR_Type {
SUCCESS = 0 , READ_SUCCESS = 0 , ALREADY_INITIALIZED = 0 , ERROR = 1 , READ_ERROR = 1 , READ_FAIL = 1 , NOT_INITIALIZED , SD_NOT_INIT , MOD_INIT_ERR , RTC_BEGIN_ERR , SD_BEGIN_ERR , NO_SD_CARD , SD_CARDTYPE_NONE , SD_DIR_OPEN_FAIL , SD_NOT_A_DIR , SD_MKDIR_FAIL , SD_RMDIR_FAIL , SD_FILE_OPEN_FAIL , SD_WRITE_FAIL , SD_APP_FAIL , SD_RENAME_FAIL , SD_RM_FAIL , AMBI_I2C_INIT_ERR , AS726X_BEGIN_ERR , AS726X_DATA_NOT_READY , NO_LDS_SENSOR , SCD30_BEGIN_ERR , TSL_BEGIN_ERR }

List of function return errors.

### 66 File Documentation

### 7.1.1 Detailed Description

Defines file used for global precompile settings.

Author

Imre Korf

Version

0.1

Date

2021-11-29

Copyright

Copyright (c) 2021

## 7.2 Defines.h

Go to the documentation of this file.

1
11 #pragma once
12
24 #define SenseBox_VERSION "0.0.1" 25
36 #define DEBUGLEVEL 3
48 #define LOGLEVEL 3
58 enum ERR_Type {
59 | //==== Successful exits ====//
60
62 | SUCCESS = 0,
64 | READ_SUCCESS = 0,
66 | ALREADY_INITIALIZED = 0,
67
68 | //==== Errors ====//
69
71 | ERROR = 1,
73 | READ_ERROR = 1,
75 | READ_FAIL = 1,
77 | NOT_INITIALIZED,
78
79 | // Logger Errors
81 | SD_NOT_INIT,
82
83 | // SBOX Errors
85 | MOD_INIT_ERR,
86
87 | // RTC Errors
89 | RTC_BEGIN_ERR,
90
91 | // SD Errors
93 | SD_BEGIN_ERR,
95 | NO_SD_CARD,
97 | SD_CARDTYPE_NONE,
99 | SD_DIR_OPEN_FAIL,
101 | SD_NOT_A_DIR,
103 | SD_MKDIR_FAIL,
105 | SD_RMDIR_FAIL,
107 | SD_FILE_OPEN_FAIL,
109 | SD_WRITE_FAIL,
111 | SD_APP_FAIL,
113 | SD_RENAME_FAIL,
115 | SD_RM_FAIL,
116
117 | // Ambimate Errors

7.3 src/Logger/Logger.h File Reference | 67
119 | AMBI_I2C_INIT_ERR,
120
121 | // AS7226X Errors
123 | AS726X_BEGIN_ERR,
125 | AS726X_DATA_NOT_READY,
126
127 | // LDS Errors
129 | NO_LDS_SENSOR,
130
131 | // SCD30 Errors
133 | SCD30_BEGIN_ERR,
134
135 | // TSL2591 Errors
137 | TSL_BEGIN_ERR,
138
139 };

## 7.3 src/Logger/Logger.h File Reference

Logger class that handles all the types of logging.

#include <Arduino.h>

#include "../Wrappers/SD/__W_SD.h"

#include "../Wrappers/Singleton/Singleton.h" #include "../Defines/Defines.h"

Classes

- class Logger

Logger singleton class. Logger is implemented as a Singleton to prevent two simultaneous logger instances from accessing the serial or sd.

Enumerations

- enum class LogLevel {
LogLevel::Error , LogLevel::Warning , LogLevel::Info , LogLevel::DataDump ,
LogLevel::__PREV }

Enum values that indicate the log level of the message.
- enum class LogType { LogType::SD = 0b01 , LogType::Serial = 0b10 , LogType::Serial_SD = 0b11 }

Enum values that indicate to which logging device should be logged.

### 7.3.1 Detailed Description

Logger class that handles all the types of logging.

Author

Imre Korf

Version

0.1

Date

2021-11-29

Copyright

Copyright (c) 2021

### 68 File Documentation

## 7.4 Logger.h

Go to the documentation of this file.

1
11 #pragma once
12
13 #include <Arduino.h>
14 #include "../Wrappers/SD/__W_SD.h"
15 #include "../Wrappers/Singleton/Singleton.h" 16 #include "../Defines/Defines.h"
17
29 enum class LogLevel {
31 | Error,
33 | Warning,
35 | Info,
37 | DataDump,
39 | __PREV
40 };
41
51 enum class LogType {
53 | SD | = 0b01,
55 | Serial | = 0b10,
57 | Serial_SD | = 0b11
58 };
61 // Logger is the master of Serial1 aswell as the SD card. 62
67 class Logger : public __iW_Module, public iSingleton{ 68 private:
72 | __W_SD* sdhandle;
73
77 | bool SER_line_ended = false;
81 | bool SD_line_ended | = false;
82
86 | LogLevel PREV_LL;
90 | const char* filepath = "";
94 | uint8_t curr_day = 32;
95
105 | void SER_print_LL_type(LogLevel LL = LogLevel::__PREV);
114 | void SD_print_LL_type(LogLevel LL = LogLevel::__PREV);
115
122 | virtual bool checkInitialized();
123
124 public:
130 | static Logger& getInstance(){
131 | static Logger Instance; | // will only be destroyed on program exit.
132 | return Instance;
133 | }
134
135 private:
136 | // remove access to the constructor of logger.
137 | Logger(){}
138 public:
139 | // Assure that only one instance can exist by removing copy and assign functions.
140 | Logger(Logger const&) | = delete; | // delete copy constructor.
141 | void operator=(Logger const&) = delete; | // remove assignment operator.
142
149 | ERR_Type init();
150
151 | // print statements.
152 | // ----------
153
164 | template<typename T>
165 | void print(T value, LogLevel LL = LogLevel::__PREV, LogType LT = LogType::Serial_SD){
166 | print(String(value).c_str(), LL, LT);
167 | }
168
179 | template<typename T>
180 | void println(T value, LogLevel LL = LogLevel::__PREV, LogType LT = LogType::Serial_SD){
181 | println(String(value).c_str(), LL, LT);
182 | }
183
194 | void print(char* s, LogLevel LL = LogLevel::__PREV, LogType LT = LogType::Serial_SD);
205 | void println(char* s, LogLevel LL = LogLevel::__PREV, LogType LT = LogType::Serial_SD);
218 | void write(char s, LogLevel LL = LogLevel::__PREV, LogType LT = LogType::Serial_SD);
223 | void breakLine(LogType LT);
228 | void dataDumpEnd(LogType LT);
229 };

## 7.5 src/Sbox/Sbox.h File Reference

Contains the highest level SenseBox wrapper class.

7.6 Sbox.h | 69

#include <Arduino.h>

#include "../Wrappers/Sensors/Ambimate/__W_Ambimate.h" #include "../Wrappers/Sensors/AS7262/__W_AS726X.h" #include "../Wrappers/Sensors/DustSensor/__W_SMUART_4L.h" #include "../Wrappers/Sensors/MAX4466/__W_MAX4466.h" #include "../Wrappers/Sensors/MIX8410/__W_MIX8410.h" #include "../Wrappers/Sensors/SCD30/__W_SCD30.h" #include "../Wrappers/Sensors/TSL2591/__W_TSL2591.h" #include "../Wrappers/RTC/__W_RTC.h"

Classes

- class SBox

SBox class containing handles to every sensor on the PCB.

### 7.5.1 Detailed Description

Contains the highest level SenseBox wrapper class.

Author

Imre Korf

Version

0.1

Date

2021-11-23

Copyright

Copyright (c) 2021

## 7.6 Sbox.h

Go to the documentation of this file.

1
11 #pragma once
12
13 /*
14 SCD30: CO2
15 MIX8410: O2
16 TSL2591: LI
17 AS7262: Spectrum
18 2314291-2: VOC + extra
19 MAX4466: Sound
20 SM-UART-04L: Fijnstof
21 */
22
23
24 /*
25 All properties:
26 O2

### 70 File Documentation

27 CO2
28 Humidity
29 Temp
30 Light Intensity (LUX)
31 Light Spectrum (6band and intensity) 32 VOC
33 eCO2
34 dB + Hz?
35 Movement (flag)
36 Dust
37 */
38
39 #include <Arduino.h>
40
41 #include "../Wrappers/Sensors/Ambimate/__W_Ambimate.h" 42 #include "../Wrappers/Sensors/AS7262/__W_AS726X.h"
43 #include "../Wrappers/Sensors/DustSensor/__W_SMUART_4L.h" 44 #include "../Wrappers/Sensors/MAX4466/__W_MAX4466.h"
45 #include "../Wrappers/Sensors/MIX8410/__W_MIX8410.h"
46 #include "../Wrappers/Sensors/SCD30/__W_SCD30.h"
47 #include "../Wrappers/Sensors/TSL2591/__W_TSL2591.h" 48 #include "../Wrappers/RTC/__W_RTC.h"
49
53 class SBox {
54 private:
55
57 | __W_Ambimate | *Ambimate;
59 | __W_AS726X | *AS7262;
61 | __W_SM_UART_4L | *LDS;
63 | __W_MAX4466 | *MAX4466;
65 | __W_MIX8410 | *MIX8410;
67 | __W_SCD30 | *SCD30;
69 | __W_TSL2591 | *TSL2591;
71 | __W_RTC | *RTC;
72
73 public:
74
81 | ERR_Type init();
82
88 | RTC_DATE_TIME getTime();
89
95 | AmbimateData getAmbimateData();
103 | ERR_Type | getColorSpectrum(ColorSpectrum& CS);
111 | ERR_Type | getLDSData(PM25_AQI_Data& Buffer);
117 | int | getMax4466();
123 | float | getO2();
129 | SCD30_DATA | getSCD30Data();
135 | TSL2591_DATA getTSL2591Data();
136 };

## 7.7 src/Wrappers/__W_Module/__iW_Module.h File Reference

Module interface for intergrating sensors and other modules.

#include <Arduino.h>

#include "../../Defines/Defines.h"

Classes

- class __iW_Module

Interface for a hardware module hardware module should be implemented as a singleton to ensure that there won't be two processes accessing the same hardware at the same time Singleton format: https←-://stackoverflow.com/a/1008289.

### 7.7.1 Detailed Description

Module interface for intergrating sensors and other modules.

7.8 __iW_Module.h | 71

Author

Imre Korf

Version

0.1

Date

2021-11-29

Copyright

Copyright (c) 2021

## 7.8 __iW_Module.h

Go to the documentation of this file.

1
11 #pragma once
12
13 #include <Arduino.h>
14 #include "../../Defines/Defines.h" 15
22 class __iW_Module {
23 protected:
28 | bool Initialized = false;
37 | virtual bool checkInitialized(){return Initialized;}
38
39 public:
46 | virtual ERR_Type init() = 0;
47 };

## 7.9 src/Wrappers/RTC/__W_RTC.h File Reference

Wrapper for the PC8563 RTC.

#include "../__W_Module/__iW_Module.h" #include "../Singleton/Singleton.h" #include <RTC.h>

Classes

- struct RTC_DATE_TIME

Struct containing the date and time of when the read() function was called.
- class __W_RTC

Singleton RTC Module.

### 72 File Documentation

### 7.9.1 Detailed Description

Wrapper for the PC8563 RTC.

Author

Imre Korf

Version

0.1

Date

2021-11-30

Copyright

Copyright (c) 2021

## 7.10 __W_RTC.h

Go to the documentation of this file.

1
11 #pragma once
12
13 #include "../__W_Module/__iW_Module.h" 14 #include "../Singleton/Singleton.h" 15
16 #include <RTC.h>
17
25 struct RTC_DATE_TIME{
27 | uint8_t | Day;
29 | uint8_t | Month;
31 | uint16_t | Year;
33 | uint8_t | Hour;
35 | uint8_t | Minute;
37 | uint8_t | Second;
38 };
44 class __W_RTC : public __iW_Module, public iSingleton{ 45 private:
49 | PCF8563 RTC;
50
57 | virtual bool checkInitialized();
58
59 | // remove access to the constructor of __W_RTC.
60 | __W_RTC(){}
61
62 public:
68 | static __W_RTC& getInstance(){
69 | static __W_RTC Instance; // will only be destroyed on program exit.
70 | return Instance;
71 | }
72 public:
73 | // Assure that only one instance can exist by removing copy and assign functions.
74 | __W_RTC(__W_RTC const&) | = delete; | // delete copy constructor.
75 | void operator=(__W_RTC const&) | = delete; | // remove assignment operator.
76
83 | ERR_Type init();
84
89 | RTC_DATE_TIME read();
90
95 | String stringDateTime();
96
101 | String stringTime();
102 };

7.11 src/Wrappers/SD/__W_SD.h File Reference | 73

## 7.11 src/Wrappers/SD/__W_SD.h File Reference

Wrapper for the SD card hardware.

#include "../__W_Module/__iW_Module.h" #include "../Singleton/Singleton.h" #include <FS.h>

#include <SD.h>

Classes

- class __W_SD

Singleton SD module.

### 7.11.1 Detailed Description

Wrapper for the SD card hardware.

Author

Imre Korf

Version

0.1

Date

2021-11-30

Copyright

Copyright (c) 2021

## 7.12 __W_SD.h

Go to the documentation of this file.

1
11 #pragma once
12
13
14 #include "../__W_Module/__iW_Module.h" 15 #include "../Singleton/Singleton.h" 16
17 #include <FS.h>
18 #include <SD.h>
19
24 class __W_SD : public __iW_Module, public iSingleton { 25 private:
27 | SDFS* ESP_SD;
28
35 | virtual bool checkInitialized();
36
37 | // remove access to the constructor of __W_SD.

### 74 File Documentation

38 | __W_SD(){}
39
40 public:
46 | static __W_SD& getInstance(){
47 | static __W_SD Instance; | // will only be destroyed on program exit.
48 | return Instance;
49 | }
50 public:
51 | // Assure that only one instance can exist by removing copy and assign functions.
52 | __W_SD(__W_SD const&) | = delete; | // delete copy constructor.
53 | void operator=(__W_SD const&) = delete; | // remove assignment operator.
54
61 | ERR_Type init();
62
71 | ERR_Type listDir(const char* dirname, uint8_t levels);
80 | ERR_Type createDir(const char* path);
88 | ERR_Type removeDir(const char* path);
97 | ERR_Type readFile(const char * path, char* buffer);
106 | ERR_Type writeFile(const char * path, const char * message);
115 | ERR_Type appendFile(const char * path, const char * message);
124 | ERR_Type renameFile(const char * path1, const char * path2);
132 | ERR_Type deleteFile(const char * path);
133
141 | ERR_Type testFileIO(const char * path);
142 };

## 7.13 src/Wrappers/Sensors/Ambimate/__W_Ambimate.h File Reference

Ambimate wrapper for the Ambimate sensor.

#include <Wire.h>

#include "../../__W_Module/__iW_Module.h"

Classes

- struct AmbimateData

struct containing the ambimate data.
- class __W_Ambimate

Singleton ambimate module.

### 7.13.1 Detailed Description

Ambimate wrapper for the Ambimate sensor.

Author

Imre Korf

Version

0.1

Date

2021-11-29

source: https://maker.pro/esp8266/tutorial/how-to-program-esp32-with-arduino-ide-and-connect-the-ambimate-ms4-multi-sensor-module

Copyright

Copyright (c) 2021

7.14 __W_Ambimate.h | 75

## 7.14 __W_Ambimate.h

Go to the documentation of this file.

1
13 #pragma once
14
15 #include <Wire.h>
16 #include "../../__W_Module/__iW_Module.h" 17
24 struct AmbimateData {
25 | union {
27 | uint8_t status;
28 | struct {
30 | uint8_t MOT_EVENT : 1; // motion event.
32 | uint8_t AUD_EVENT : 1; // audio event.
33 | uint8_t | : 5; // padding.
35 | uint8_t PIR_EVENT : 1; // PIR event.
36 | };
37 | };
39 | float temperatureC;
41 | float Humidity;
43 | float batVolts;
45 | uint16_t light;
47 | uint16_t audio;
49 | uint16_t eco2_ppm;
51 | uint16_t voc_ppm;
52 };
58 class __W_Ambimate : public __iW_Module, public iSingleton { 59 private:
63 | uint8_t opt_sensors;
64
71 | virtual bool checkInitialized();
72
73 | // remove access to the constructor of __W_Ambimate.
74 | __W_Ambimate(){}
75
76 public:
82 | static __W_Ambimate& getInstance(){
83 | static __W_Ambimate Instance; | // will only be destroyed on program exit.
84 | return Instance;
85 | }
86 | // Assure that only one instance can exist by removing copy and assign functions.
87 | __W_Ambimate(__W_Ambimate const&) | = delete; | // delete copy constructor.
88 | void operator=(__W_Ambimate const&) = delete; | // remove assignment operator.
89
96 | ERR_Type init();
97
103 | AmbimateData read();
104
110 | uint8_t get_opt_sensors();
111 };

## 7.15 src/Wrappers/Sensors/AS7262/__W_AS726X.cpp File Reference

TSL2591 wrapper for the TSL2591 adafruit library.

#include <Arduino.h>

#include "__W_AS726X.h"

#include "../../../Logger/Logger.h"

### 7.15.1 Detailed Description

TSL2591 wrapper for the TSL2591 adafruit library.

Author

Imre Korf

### 76 File Documentation

Version

0.1

Date

2021-11-23

Copyright

Copyright (c) 2021

## 7.16 __W_AS726X.h

1
11 #pragma once
12
13 #include <Adafruit_AS726x.h>
14 #include "../../__W_Module/__iW_Module.h" 15
22 struct ColorSpectrum {
24 | float Violet;
26 | float Blue;
28 | float Green;
30 | float Yellow;
32 | float Orange;
34 | float Red;
35 };
41 class __W_AS726X : public __iW_Module, public iSingleton { 42 private:
44 | Adafruit_AS726x AS7262;
45
52 | virtual bool checkInitialized();
53
54 | // remove access to the constructor of __W_AS726X.
55 | __W_AS726X(){}
56 public:
62 | static __W_AS726X& getInstance(){
63 | static __W_AS726X Instance; | // will only be destroyed on program exit.
64 | return Instance;
65 | }
66 | // Assure that only one instance can exist by removing copy and assign functions.
67 | __W_AS726X(__W_AS726X const&) | = delete; | // delete copy constructor.
68 | void operator=(__W_AS726X const&) = delete; | // remove assignment operator.
69
76 | ERR_Type init();
77
81 | void setDrvLed(bool B);
85 | void setDrvCurrent(uint8_t V);
89 | void indicateLED(bool B);
93 | void setIndicateCurrent(uint8_t V);
94
99 | void setGain(uint8_t gain);
104 | void setIntegrationTime(uint8_t time);
110 | void setConversionType(uint8_t type);
111
115 | void startMeasurement();
121 | bool checkDataReady();
122
127 | void getMeasurements(ColorSpectrum* CS);
132 | uint8_t getTemperature();
133 };

## 7.17 src/Wrappers/Sensors/DustSensor/__W_SMUART_4L.h File Reference

SM_UART_4L wrapper for the PM25AQI adafruit library.

#include <Adafruit_PM25AQI.h>

#include "../../__W_Module/__iW_Module.h"

7.18 __W_SMUART_4L.h | 77

Classes

- class __W_SM_UART_4L

Singleton LDS module.

### 7.17.1 Detailed Description

SM_UART_4L wrapper for the PM25AQI adafruit library.

Author

Imre Korf

Version

0.1

Date

2021-11-29

Copyright

Copyright (c) 2021

## 7.18 __W_SMUART_4L.h

Go to the documentation of this file.

1
11 #pragma once
12
13 #include <Adafruit_PM25AQI.h>
14 #include "../../__W_Module/__iW_Module.h"
15
19 class __W_SM_UART_4L : public __iW_Module, public iSingleton { 20 private:
22 | Adafruit_PM25AQI aqi;
23
30 | virtual bool checkInitialized();
31
32 | // remove access to the constructor of __W_SM_UART_4L.
33 | __W_SM_UART_4L(){}
34 public:
40 | static __W_SM_UART_4L& getInstance(){
41 | static __W_SM_UART_4L Instance; | // will only be destroyed on program exit.
42 | return Instance;
43 | }
44 | // Assure that only one instance can exist by removing copy and assign functions.
45 | __W_SM_UART_4L(__W_SM_UART_4L const&) | = delete; | // delete copy constructor.
46 | void operator=(__W_SM_UART_4L const&) = delete; | // remove assignment operator.
47
54 | ERR_Type init();
55
63 | ERR_Type read(PM25_AQI_Data& data);
64 };

### 78 File Documentation

## 7.19 src/Wrappers/Sensors/MAX4466/__W_MAX4466.h File Reference

MAX4466 wrapper for the MAX4466 sensor.

#include "../../__W_Module/__iW_Module.h"

Classes

- class __W_MAX4466

Singleton MAX4466 module.

### 7.19.1 Detailed Description

MAX4466 wrapper for the MAX4466 sensor.

Author

Imre Korf

Version

0.1

Date

2021-11-23

source: https://blog.yavilevich.com/2016/08/arduino-sound-level-meter-and-spectrum-analyzer/

Copyright

Copyright (c) 2021

## 7.20 __W_MAX4466.h

Go to the documentation of this file.

1
13 #pragma once
14
15 #include "../../__W_Module/__iW_Module.h"
16
20 class __W_MAX4466 : public __iW_Module, public iSingleton { 21 private:
28 | virtual bool checkInitialized();
29
30 | // remove access to the constructor of __W_MAX4466.
31 | __W_MAX4466(){}
32 public:
38 | static __W_MAX4466& getInstance(){
39 | static __W_MAX4466 Instance; // will only be destroyed on program exit.
40 | return Instance;
41 | }
42 | // Assure that only one instance can exist by removing copy and assign functions.
43 | __W_MAX4466(__W_MAX4466 const&) | = delete; | // delete copy constructor.
44 | void operator=(__W_MAX4466 const&) | = delete; | // remove assignment operator.
45
52 | ERR_Type init();
53
59 | int read();
60
61 };

7.21 src/Wrappers/Sensors/MIX8410/__W_MIX8410.h File Reference | 79

## 7.21 src/Wrappers/Sensors/MIX8410/__W_MIX8410.h File Reference

MIX8410 wrapper for the MIX8410 sensor.

#include "../../__W_Module/__iW_Module.h"

Classes

- class __W_MIX8410

Singleton MIX8410 module.

### 7.21.1 Detailed Description

MIX8410 wrapper for the MIX8410 sensor.

Author

Imre Korf

Version

0.1

Date

2021-11-23

Copyright

Copyright (c) 2021

## 7.22 __W_MIX8410.h

Go to the documentation of this file.

1
11 #pragma once
12
13 #include "../../__W_Module/__iW_Module.h"
14
18 class __W_MIX8410 : public __iW_Module, public iSingleton { 19
20 private:
24 | const float VRefer = 3.3;
28 | const int pinAdc | = A0;
29
30 | // remove access to the constructor of __W_MIX8410.
31 | __W_MIX8410(){}
32 public:
38 | static __W_MIX8410& getInstance(){
39 | static __W_MIX8410 Instance; // will only be destroyed on program exit.
40 | return Instance;
41 | }
42 | // Assure that only one instance can exist by removing copy and assign functions.
43 | __W_MIX8410(__W_MIX8410 const&) | = delete; | // delete copy constructor.
44 | void operator=(__W_MIX8410 const&) | = delete; | // remove assignment operator.
45
52 | ERR_Type init(){return SUCCESS;}
58 | float readConcentration();
64 | float readO2Vout();
65 };

### 80 File Documentation

## 7.23 src/Wrappers/Sensors/SCD30/__W_SCD30.h File Reference

SCD30 wrapper for the SCD30 sensor.

#include <Wire.h>

#include <SparkFun_SCD30_Arduino_Library.h> #include "../../__W_Module/__iW_Module.h"

Classes

- struct SCD30_DATA

Struct containg the SCD30 Data.
- class __W_SCD30

Singleton SCD30 module.

### 7.23.1 Detailed Description

SCD30 wrapper for the SCD30 sensor.

Author

Imre Korf

Version

0.1

Date

2021-11-29

Copyright

Copyright (c) 2021

## 7.24 __W_SCD30.h

Go to the documentation of this file.

1
11 #pragma once
12
13 #include <Wire.h>
14 #include <SparkFun_SCD30_Arduino_Library.h> 15 #include "../../__W_Module/__iW_Module.h" 16
22 struct SCD30_DATA {
24 | uint16_t CO2;
26 | float Temperature;
28 | float Humidity;
29 };
35 class __W_SCD30 : public __iW_Module, public iSingleton { 36 private:
38 | SCD30 airSensor;

7.25 src/Wrappers/Sensors/TSL2591/__W_TSL2591.h File Reference | 81

39
43 | bool autoCalibrate = false;
50 | virtual bool checkInitialized();
51
52 | // remove access to the constructor of __W_SCD30
53 | __W_SCD30(){}
54 public:
60 | static __W_SCD30& getInstance(){
61 | static __W_SCD30 Instance; // will only be destroyed on program exit.
62 | return Instance;
63 | }
64 | // Assure that only one instance can exist by removing copy and assign functions.
65 | __W_SCD30(__W_SCD30 const&) | = delete; | // delete copy constructor.
66 | void operator=(__W_SCD30 const&) | = delete; | // remove assignment operator.
67
73 | SCD30_DATA read();
74
88 | ERR_Type init(bool autoCalibrate);
89
96 | ERR_Type init();
97
104 | bool dataAvailable();
105
111 | uint16_t getCO2();
117 | float getTemperature();
123 | float getHumidity();
124
125 | // Options:
131 | void setMeasurementsInterval(uint16_t seconds);
132
140 | bool getMeasurementsInterval(uint16_t& seconds);
141
147 | void setAltitudeCompensation(uint16_t altitude);
148
156 | bool getAltitudeCompensation(uint16_t& altitude);
157
163 | void setAmbientPressure(uint16_t Pressure);
164
170 | void setTemperatureOffset(float offset);
171
179 | bool getTemperatureOffset(float& offset);
180
187 | bool getAutoSelfCalibration();
188
196 | bool getForcedRecalibration(uint16_t& settingVal);
197
205 | bool getFirmwareVersion(uint16_t& settingVal);
206 };

## 7.25 src/Wrappers/Sensors/TSL2591/__W_TSL2591.h File Reference

TSL2591 wrapper for the TSL2591 adafruit library.

#include <Wire.h>

#include <Adafruit_Sensor.h>

#include <Adafruit_TSL2591.h>

#include "../../__W_Module/__iW_Module.h"

Classes

- struct TSL2591_DATA

Struct containing the TSL2591 data.
- class __W_TSL2591

Singleton TSL2591 module.

### 82 File Documentation

### 7.25.1 Detailed Description

TSL2591 wrapper for the TSL2591 adafruit library.

Author

Imre Korf

Version

0.1

Date

2021-11-23

Copyright

Copyright (c) 2021

## 7.26 __W_TSL2591.h

Go to the documentation of this file.

1
11 #pragma once
12
13 #include <Wire.h>
14 #include <Adafruit_Sensor.h>
15 #include <Adafruit_TSL2591.h>
16
17 #include "../../__W_Module/__iW_Module.h" 18
25 struct TSL2591_DATA {
27 | uint16_t visible;
29 | uint16_t ir;
31 | uint16_t full;
32 };
38 class __W_TSL2591 : public __iW_Module, public iSingleton { 39 private:
41 | Adafruit_TSL2591 tsl;
42
49 | virtual bool checkInitialized();
50 | // remove access to the constructor of __W_TSL2591.
51 | __W_TSL2591() : tsl(2591){} // pass in a number for the sensor identifier (for your use later).
52 public:
58 | static __W_TSL2591& getInstance(){
59 | static __W_TSL2591 Instance; // will only be destroyed on program exit.
60 | return Instance;
61 | }
62 | // Assure that only one instance can exist by removing copy and assign functions.
63 | __W_TSL2591(__W_TSL2591 const&) | = delete; | // delete copy constructor.
64 | void operator=(__W_TSL2591 const&) | = delete; | // remove assignment operator.
65
72 | ERR_Type init();
73
78 | void displaySensorDetails();
79
86 | uint16_t getLuminosity(uint8_t spectrum = TSL2591_VISIBLE);
92 | TSL2591_DATA getFullLuminosity();
93
100 | float getLux(uint16_t full, uint16_t ir);
101 };

## 7.27 src/Wrappers/Singleton/Singleton.h File Reference

Singleton template interface.

7.28 Singleton.h | 83

Classes

- class iSingleton

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

### 7.27.1 Detailed Description

Singleton template interface.

Author

Imre Korf

Version

0.1

Date

2021-12-06

Copyright

Copyright (c) 2021

## 7.28 Singleton.h

Go to the documentation of this file.

1
12 #pragma once
13
19 class iSingleton{
20 /*
21 public:
22 | // make sure that only one instance is created and accessible during runtime
23 | static Derived& getInstance(){
24 | static Derived Instance; | // will only be destroyed on program exit
25 | return Instance;
26 | }
27 private:
28 | // remove access to the constructor of derived
29 | Derived(){}
30 public:
31 | // Assure that only one instance can exist by removing copy and assign functions
32 | Derived(Derived const&) | = delete; | // delete copy constructor
33 | void operator=(Derived const&) | = delete; | // remove assignment operator
34 */
35 };

### 84 File Documentation

# Index

__PREV
Global Enumerations, 12
__W_AS726X, 19
checkDataReady, 20
getInstance, 21
getMeasurements, 21
getTemperature, 21
indicateLED, 21
init, 22
setConversionType, 22
setDrvCurrent, 22
setDrvLed, 23
setGain, 23
setIndicateCurrent, 23
setIntegrationTime, 23
__W_Ambimate, 17
get_opt_sensors, 18
getInstance, 18
init, 18
read, 19
__W_MAX4466, 24
getInstance, 25
init, 25
read, 25
__W_MIX8410, 26
getInstance, 27
init, 27
readConcentration, 27
readO2Vout, 28
__W_RTC, 28
getInstance, 29
init, 29
read, 29
stringDateTime, 30
stringTime, 30
__W_SCD30, 30
dataAvailable, 32
getAltitudeCompensation, 32 getAutoSelfCalibration, 32 getCO2, 33
getFirmwareVersion, 33
getForcedRecalibration, 33 getHumidity, 34
getInstance, 34
getMeasurementsInterval, 34 getTemperature, 34
getTemperatureOffset, 35
init, 35
read, 36

setAltitudeCompensation, 36 setAmbientPressure, 36
setMeasurementsInterval, 37 setTemperatureOffset, 37
__W_SD, 37
appendFile, 39
createDir, 39
deleteFile, 39
getInstance, 40
init, 40
listDir, 40
readFile, 41
removeDir, 41
renameFile, 42
testFileIO, 42
writeFile, 43
__W_SM_UART_4L, 43
getInstance, 44
init, 44
read, 44
__W_TSL2591, 45
getFullLuminosity, 46
getInstance, 46
getLuminosity, 46
getLux, 47
init, 47
__iW_Module, 15
checkInitialized, 16
init, 16

ALREADY_INITIALIZED
Global Enumerations, 11
AMBI_I2C_INIT_ERR
Global Enumerations, 11
AmbimateData, 48
AUD_EVENT, 48
audio, 48
batVolts, 48
eco2_ppm, 49
Humidity, 49
light, 49
MOT_EVENT, 49
PIR_EVENT, 49
status, 49
temperatureC, 49
voc_ppm, 49
appendFile
__W_SD, 39
AS726X_BEGIN_ERR
Global Enumerations, 11

### 86 INDEX

AS726X_DATA_NOT_READY
Global Enumerations, 11
AUD_EVENT
AmbimateData, 48
audio
AmbimateData, 48

batVolts
AmbimateData, 48
breakLine
Logger, 53

checkDataReady
__W_AS726X, 20
checkInitialized
__iW_Module, 16
CO2
SCD30_DATA, 62
ColorSpectrum, 50
createDir
__W_SD, 39

dataAvailable
__W_SCD30, 32
DataDump
Global Enumerations, 12
dataDumpEnd
Logger, 53
Day
RTC_DATE_TIME, 57
DEBUGLEVEL
Global defines,
9
deleteFile
__W_SD, 39

eco2_ppm
AmbimateData, 49
ERR_Type
Global Enumerations, 10
ERROR
Global Enumerations, 11
Error
Global Enumerations, 12

get_opt_sensors
__W_Ambimate, 18
getAltitudeCompensation
__W_SCD30, 32
getAmbimateData
SBox, 59
getAutoSelfCalibration
__W_SCD30, 32
getCO2
__W_SCD30, 33
getColorSpectrum
SBox, 59
getFirmwareVersion
__W_SCD30, 33
getForcedRecalibration

__W_SCD30, 33
getFullLuminosity
__W_TSL2591, 46
getHumidity
__W_SCD30, 34
getInstance
__W_AS726X, 21
__W_Ambimate, 18
__W_MAX4466, 25
__W_MIX8410, 27
__W_RTC, 29
__W_SCD30, 34
__W_SD, 40
__W_SM_UART_4L, 44
__W_TSL2591, 46
Logger, 53
getLDSData
SBox, 59
getLuminosity
__W_TSL2591, 46
getLux
__W_TSL2591, 47
getMax4466
SBox, 60
getMeasurements
__W_AS726X, 21
getMeasurementsInterval
__W_SCD30, 34
getO2
SBox, 60
getSCD30Data
SBox, 60
getTemperature
__W_AS726X, 21
__W_SCD30, 34
getTemperatureOffset
__W_SCD30, 35
getTime
SBox, 60
getTSL2591Data
SBox, 61
Global defines,
9
DEBUGLEVEL,
9
LOGLEVEL, 10
Global Enumerations, 10
__PREV, 12
ALREADY_INITIALIZED, 11
AMBI_I2C_INIT_ERR, 11
AS726X_BEGIN_ERR, 11
AS726X_DATA_NOT_READY, 11
DataDump, 12
ERR_Type, 10
ERROR, 11
Error, 12
Info, 12
LogLevel, 11
LogType, 12
MOD_INIT_ERR, 11

INDEX | 87

NO_LDS_SENSOR, 11
NO_SD_CARD, 11
NOT_INITIALIZED, 11
READ_ERROR, 11
READ_FAIL, 11
READ_SUCCESS, 11
RTC_BEGIN_ERR, 11
SCD30_BEGIN_ERR, 11
SD, 12
SD_APP_FAIL, 11
SD_BEGIN_ERR, 11
SD_CARDTYPE_NONE, 11
SD_DIR_OPEN_FAIL, 11
SD_FILE_OPEN_FAIL, 11
SD_MKDIR_FAIL, 11
SD_NOT_A_DIR, 11
SD_NOT_INIT, 11
SD_RENAME_FAIL, 11
SD_RM_FAIL, 11
SD_RMDIR_FAIL, 11
SD_WRITE_FAIL, 11
Serial, 12
Serial_SD, 12
SUCCESS, 11
TSL_BEGIN_ERR, 11
Warning, 12
Global structures, 12

Hour
RTC_DATE_TIME, 57
Humidity
AmbimateData, 49
SCD30_DATA, 62

indicateLED
__W_AS726X, 21
Info
Global Enumerations, 12
init
__W_AS726X, 22
__W_Ambimate, 18
__W_MAX4466, 25
__W_MIX8410, 27
__W_RTC, 29
__W_SCD30, 35
__W_SD, 40
__W_SM_UART_4L, 44
__W_TSL2591, 47
__iW_Module, 16
Logger, 53
SBox, 61
iSingleton, 51

light
AmbimateData, 49
listDir
__W_SD, 40
Logger, 51
breakLine, 53

dataDumpEnd, 53
getInstance, 53
init, 53
print, 54
println, 55
write, 56
LOGLEVEL
Global defines, 10
LogLevel
Global Enumerations, 11
LogType
Global Enumerations, 12

Minute
RTC_DATE_TIME, 57
MOD_INIT_ERR
Global Enumerations, 11
Month
RTC_DATE_TIME, 58
MOT_EVENT
AmbimateData, 49

NO_LDS_SENSOR
Global Enumerations, 11
NO_SD_CARD
Global Enumerations, 11
NOT_INITIALIZED
Global Enumerations, 11

PIR_EVENT
AmbimateData, 49
print
Logger, 54
println
Logger, 55

read
__W_Ambimate, 19
__W_MAX4466, 25
__W_RTC, 29
__W_SCD30, 36
__W_SM_UART_4L, 44
READ_ERROR
Global Enumerations, 11
READ_FAIL
Global Enumerations, 11
READ_SUCCESS
Global Enumerations, 11
readConcentration
__W_MIX8410, 27
readFile
__W_SD, 41
readO2Vout
__W_MIX8410, 28
removeDir
__W_SD, 41
renameFile
__W_SD, 42
RTC_BEGIN_ERR

### 88 INDEX

Global Enumerations, 11
RTC_DATE_TIME, 57
Day, 57
Hour, 57
Minute, 57
Month, 58
Second, 58
Year, 58

SBox, 58
getAmbimateData, 59
getColorSpectrum, 59
getLDSData, 59
getMax4466, 60
getO2, 60
getSCD30Data, 60
getTime, 60
getTSL2591Data, 61
init, 61
SCD30_BEGIN_ERR
Global Enumerations, 11
SCD30_DATA, 61
CO2, 62
Humidity, 62
Temperature, 62
SD
Global Enumerations, 12
SD_APP_FAIL
Global Enumerations, 11
SD_BEGIN_ERR
Global Enumerations, 11
SD_CARDTYPE_NONE
Global Enumerations, 11
SD_DIR_OPEN_FAIL
Global Enumerations, 11
SD_FILE_OPEN_FAIL
Global Enumerations, 11
SD_MKDIR_FAIL
Global Enumerations, 11
SD_NOT_A_DIR
Global Enumerations, 11
SD_NOT_INIT
Global Enumerations, 11
SD_RENAME_FAIL
Global Enumerations, 11
SD_RM_FAIL
Global Enumerations, 11
SD_RMDIR_FAIL
Global Enumerations, 11
SD_WRITE_FAIL
Global Enumerations, 11
Second
RTC_DATE_TIME, 58
Serial
Global Enumerations, 12
Serial_SD
Global Enumerations, 12
setAltitudeCompensation
__W_SCD30, 36

setAmbientPressure
__W_SCD30, 36
setConversionType
__W_AS726X, 22
setDrvCurrent
__W_AS726X, 22
setDrvLed
__W_AS726X, 23
setGain
__W_AS726X, 23
setIndicateCurrent
__W_AS726X, 23
setIntegrationTime
__W_AS726X, 23
setMeasurementsInterval
__W_SCD30, 37
setTemperatureOffset
__W_SCD30, 37
src/Defines/Defines.h, 65
, 66
src/Logger/Logger.h, 67
, 68
src/Sbox/Sbox.h, 68
, 69
src/Wrappers/__W_Module/__iW_Module.h, 70 , 71
src/Wrappers/RTC/__W_RTC.h, 71
, 72
src/Wrappers/SD/__W_SD.h, 73 src/Wrappers/Sensors/Ambimate/__W_Ambimate.h, 74

, 75
src/Wrappers/Sensors/AS7262/__W_AS726X.cpp, 75 src/Wrappers/Sensors/AS7262/__W_AS726X.h, 76 src/Wrappers/Sensors/DustSensor/__W_SMUART_4L.h, 76

, 77
src/Wrappers/Sensors/MAX4466/__W_MAX4466.h, 78 src/Wrappers/Sensors/MIX8410/__W_MIX8410.h, 79 src/Wrappers/Sensors/SCD30/__W_SCD30.h, 80 src/Wrappers/Sensors/TSL2591/__W_TSL2591.h, 81 ,
82
src/Wrappers/Singleton/Singleton.h, 82
, 83
status
AmbimateData, 49
stringDateTime
__W_RTC, 30
stringTime
__W_RTC, 30
SUCCESS
Global Enumerations, 11

Temperature
SCD30_DATA, 62
temperatureC
AmbimateData, 49
testFileIO
__W_SD, 42
TSL2591_DATA, 62
TSL_BEGIN_ERR
Global Enumerations, 11

voc_ppm
AmbimateData, 49

Warning

INDEX | 89

Global Enumerations, 12
write
Logger, 56
writeFile
__W_SD, 43

Year
RTC_DATE_TIME, 58

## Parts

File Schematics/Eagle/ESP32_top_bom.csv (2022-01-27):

Comment | Designator | Footprint | LCSC Part #
0ohm | DIS | SJ
1k | R11 R17 R18 | R0805 | C11702
1uF | C8 | C0402 | C52923
4.7k | R1 | R0402 | C25900
4.7uF | C5 | C0402 | C23733
5.1k | R4 R5 | R0402 | C25905
7pF | C4 C11 | C0402 | C1577
10k | R2 R3 R6 R10 R12 R13 R14 R15 R16 R19 R21 R22 R23 R24 R29 | R0402 | C25744
10uF | C10 | A/3216-18R | C7171
22uF | C15 C18 | C0603 | C59461
32.768KHZ | G1 | 32.768KHZ | C97602
78L05G | VR1 | SOT89 | C71136
100k | R7 R8 | R0402 | C25741
100nF | C2 C3 C6 C7 C9 C13 C17 C19 C21 | C0402 | C1525
100uF | C16 | B/3528-21W | C16133
220uF | C14 | D/7343-31R | C7231
330nF | C1 | C0805 | C1740
AMS1117-3.3 | VR2 | SOT223 | C6186
AO3400A | Q1 Q2 Q3 Q4 | SOT23 | C20917
C2286 | 3V3 5V | CHIPLED_0603 | C2286
CP2102 | IC1 | MLP28 | C6568
ESP32-WROOM-32 | U1 | MODULE_ESP32-WROOM-32 | C529577
JST-PH-4 | AS7262 I2C_EXT MAX4466 MIX8410 SCD30 TSL2591 VOC_AE VOC_DAT | JST-PH-4 | C50137
LESD5D5.0CT1G | D1 D3 D4 | LESD5D5.0CT1G | C383211
M7 | D2 D5 | DO-214AC | C95872
M50-3600542 | LDS | M503600542
PCF8563T | RTC1 | SOIC8 | C7440
SS8050 | T1 T2 | SOT23-BEC | C2150
TF-115 | TF115 | TF-115 | C266620
TS-1187A-C-E-B | BOOT RST | TS-1187A-C-E-B | C318887
TYPE-C-31-M-12 | J2 | HRO_TYPE-C-31-M-12 | C165948
YELLOW | LED | CHIPLED_0603 | C72038

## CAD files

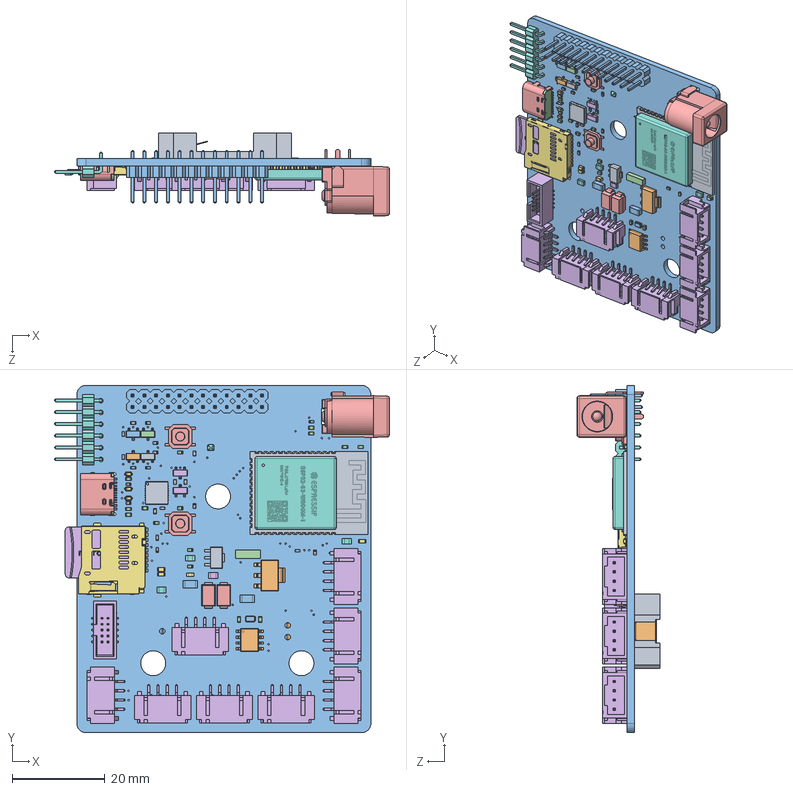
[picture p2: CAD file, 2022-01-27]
Schematics/Eagle/Models/PCB-ESP32.step.SLDASM
72.3 x 75.0 x 17.9 mm
base.step
connector_plus.step
connector_minus.step
Part 23.step
Part 30.step
Part 28.step
Part 27.step
Part 29.step
Part 24.step
Part 25.step
Part 26.step
Part 19.step
Part 18.step
Part 17.step
Part 22.step
Part 20.step
Part 21.step
Part 15.step
Part 16.step
Part 14.step
Part 13.step
Part 10.step
Part 11.step
Part 12.step
Part 8.step
Part 2.step
Part 9.step
Part 7.step
Part 6.step
Part 3.step
Part 4.step
Part 5.step
Part 1.step
ConPins.step
PcbPins.step
Mold.step
Frame.step
sd.step.STEP.step
slot.step.STEP.step
MOV_SD.step.STEP.step
MOV_SD-0.step.STEP.step
MOV_SD-1.step.STEP.step
MOV_SD-2.step.STEP.step
MOV_SD-3.step.STEP.step
MOV_SD-4.step.STEP.step
MOV_SD-5.step.STEP.step
MOV_SD-6.step.STEP.step
MOV_SD-7.step.STEP.step
MOV_SD-8.step.STEP.step
MOV_SD-9.step.STEP.step
MOV_SD-10.step.STEP.step
MOV_SD-11.step.STEP.step
MOV_SD-12.step.STEP.step
MOV_SD-13.step.STEP.step
MOV_SD-14.step.STEP.step
MOV_SD-15.step.STEP.step
SC-20S_Body.step
SC-20S_pins.step
SC-20S_can.step
SC-20S_can_seal.step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

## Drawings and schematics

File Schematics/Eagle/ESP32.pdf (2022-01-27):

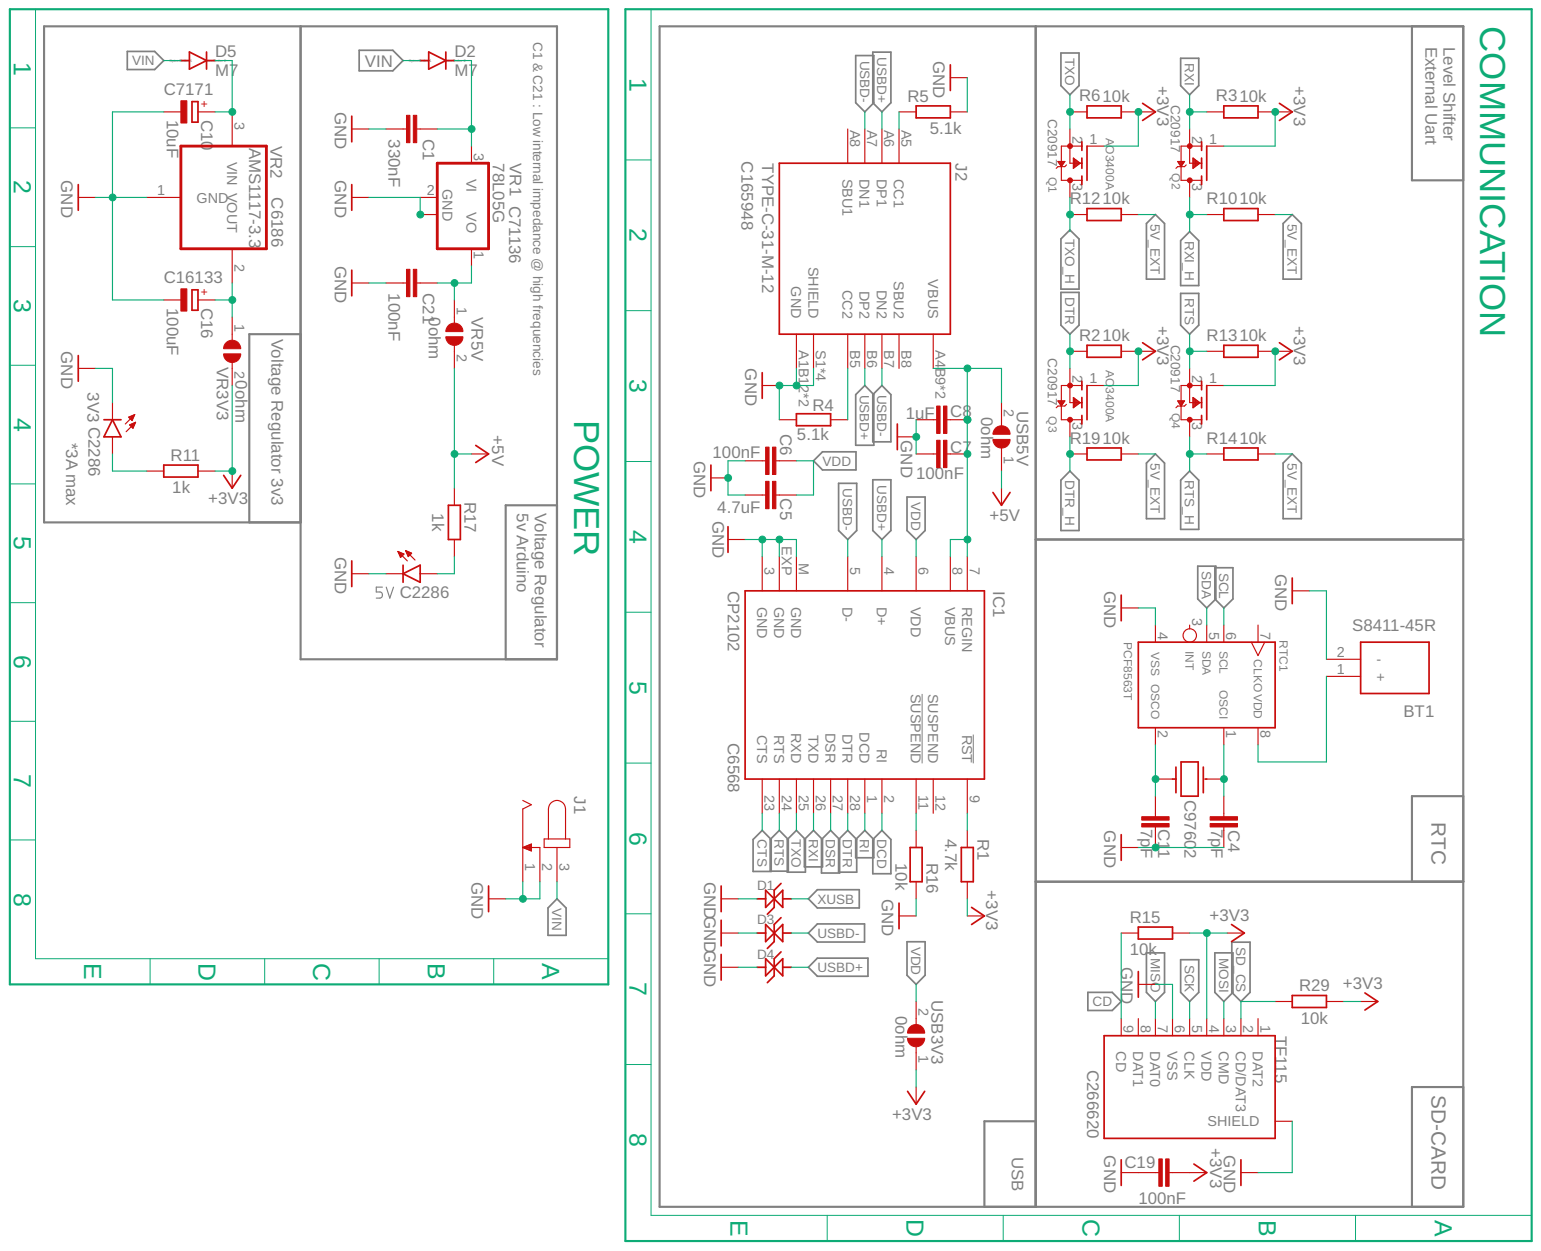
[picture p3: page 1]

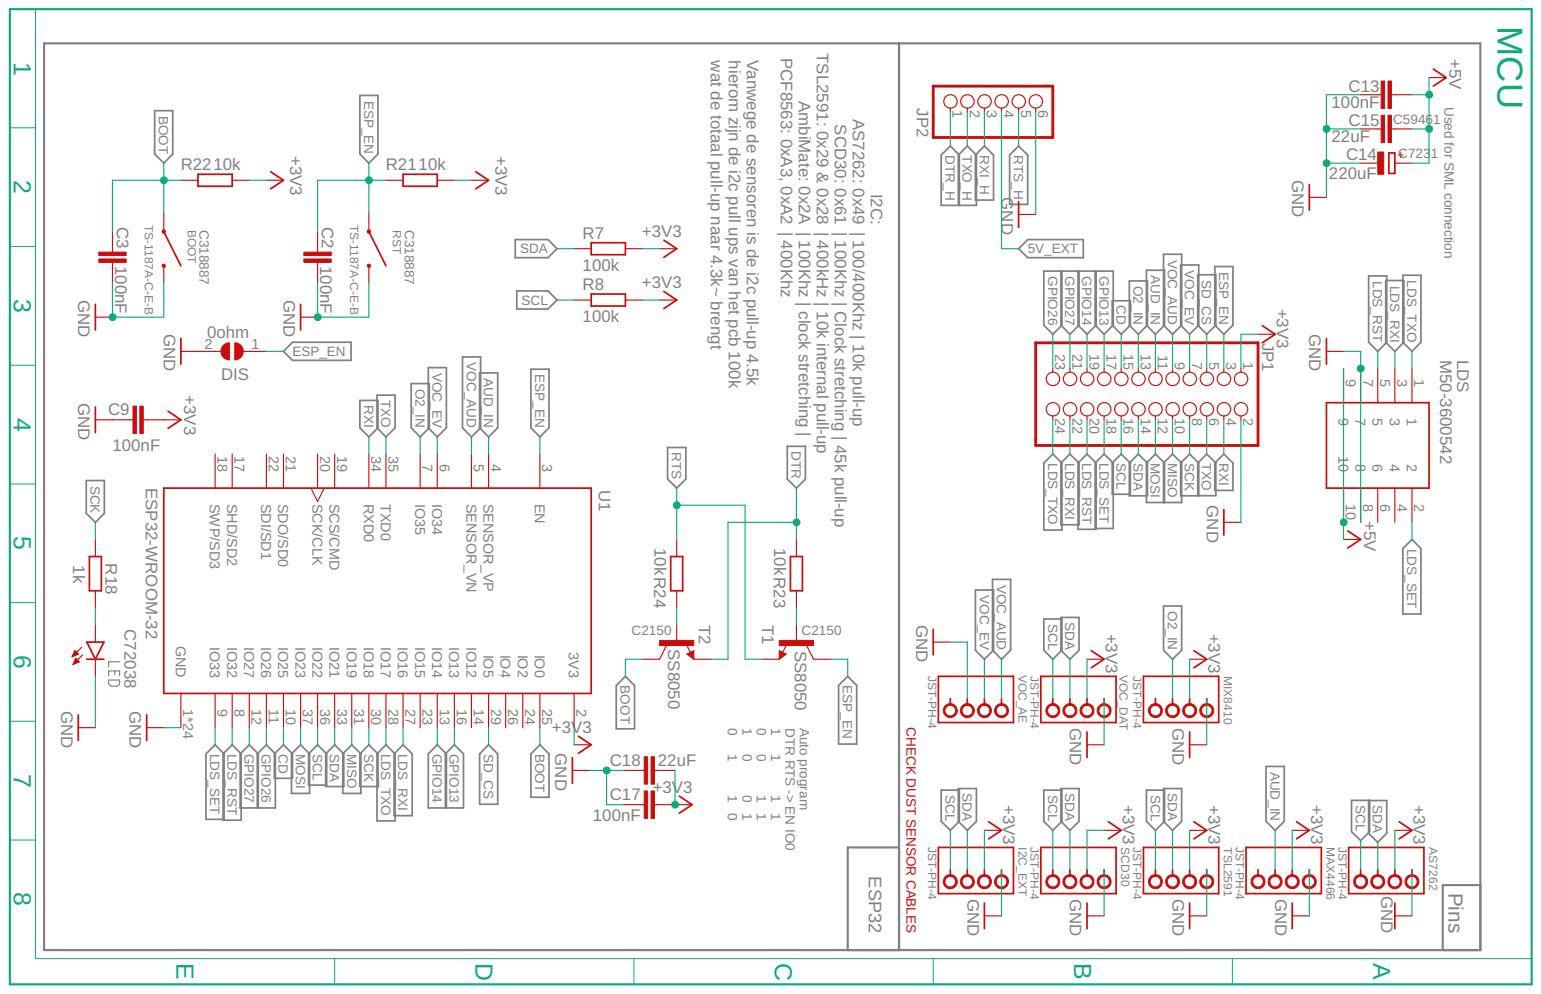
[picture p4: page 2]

ESP32 Vanwege de sensoren is de i2c pull-up 4.5k hierom zijn de i2c pull ups van het pcb 100k wat de totaal pull-up naar 4.3k~ brengt

Used for SML connection

100Khz | Clock stretching | 45k pull-up

JST-PH-4 JST-PH-4 +3V3 GND GND

CHECK DUST SENSOR CABLES

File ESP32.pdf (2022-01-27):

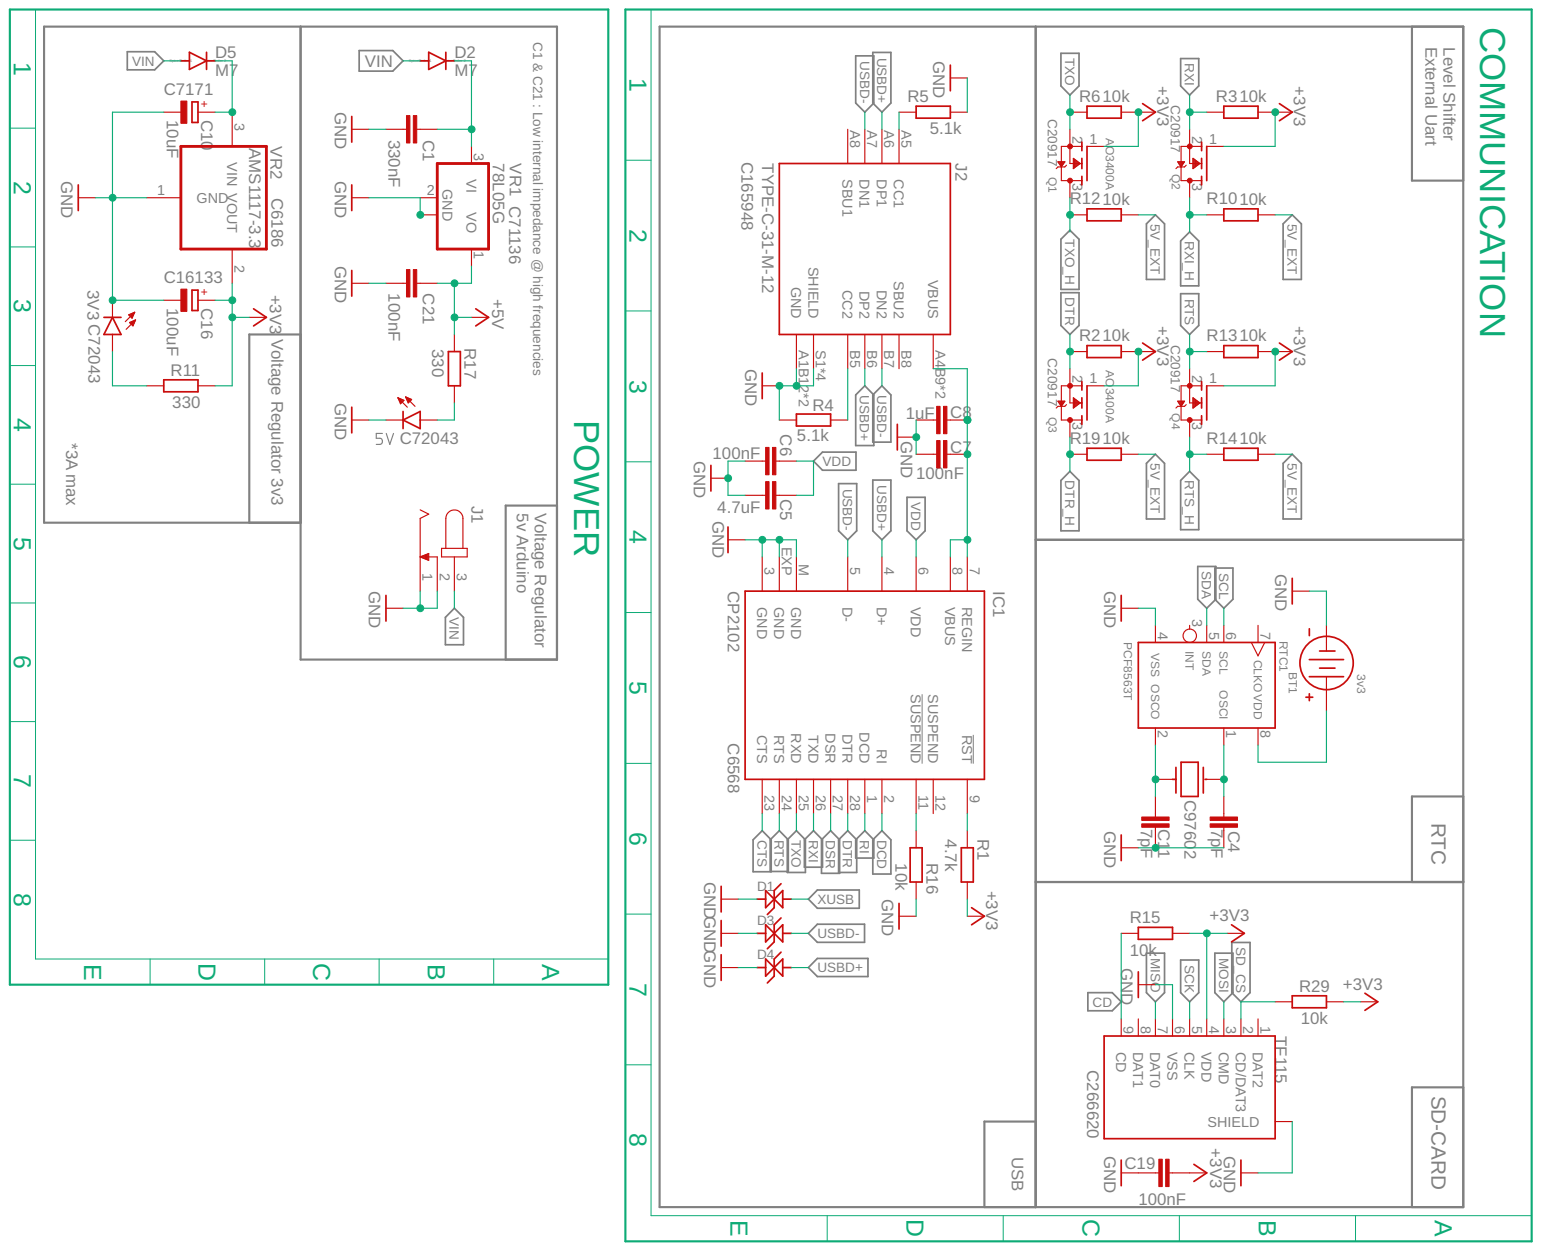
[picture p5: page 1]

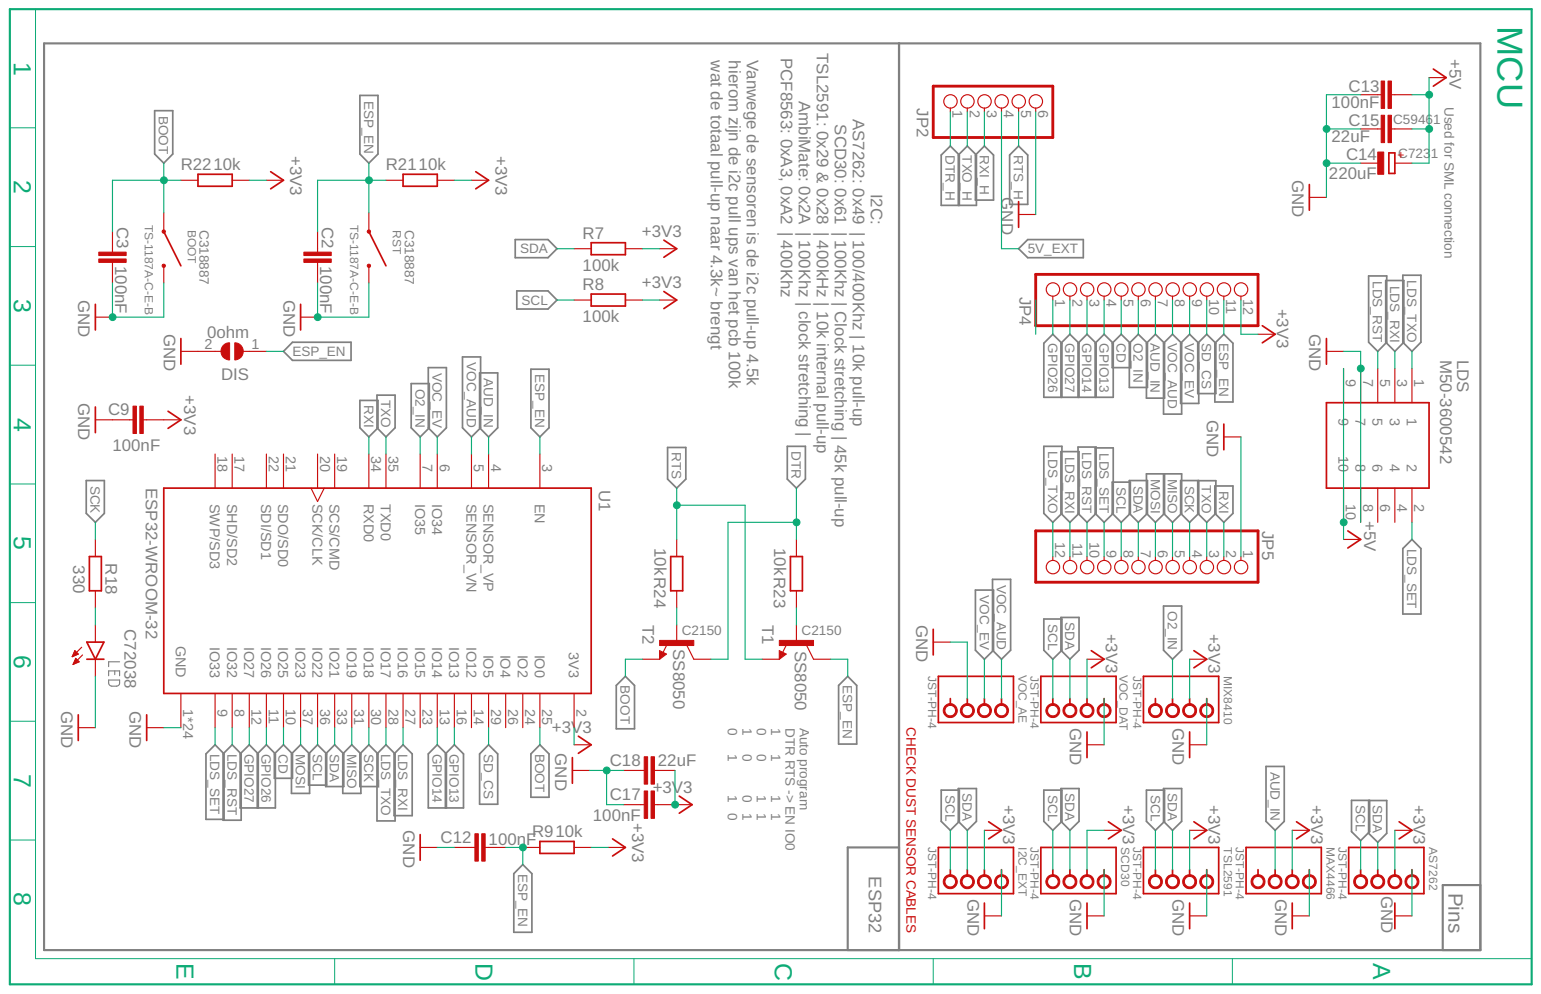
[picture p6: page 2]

ESP32 Vanwege de sensoren is de i2c pull-up 4.5k hierom zijn de i2c pull ups van het pcb 100k wat de totaal pull-up naar 4.3k~ brengt

Used for SML connection

100Khz | Clock stretching | 45k pull-up

JST-PH-4 JST-PH-4 +3V3 GND GND

CHECK DUST SENSOR CABLES

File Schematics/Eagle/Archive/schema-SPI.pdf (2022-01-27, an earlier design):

## Uart Selector

A

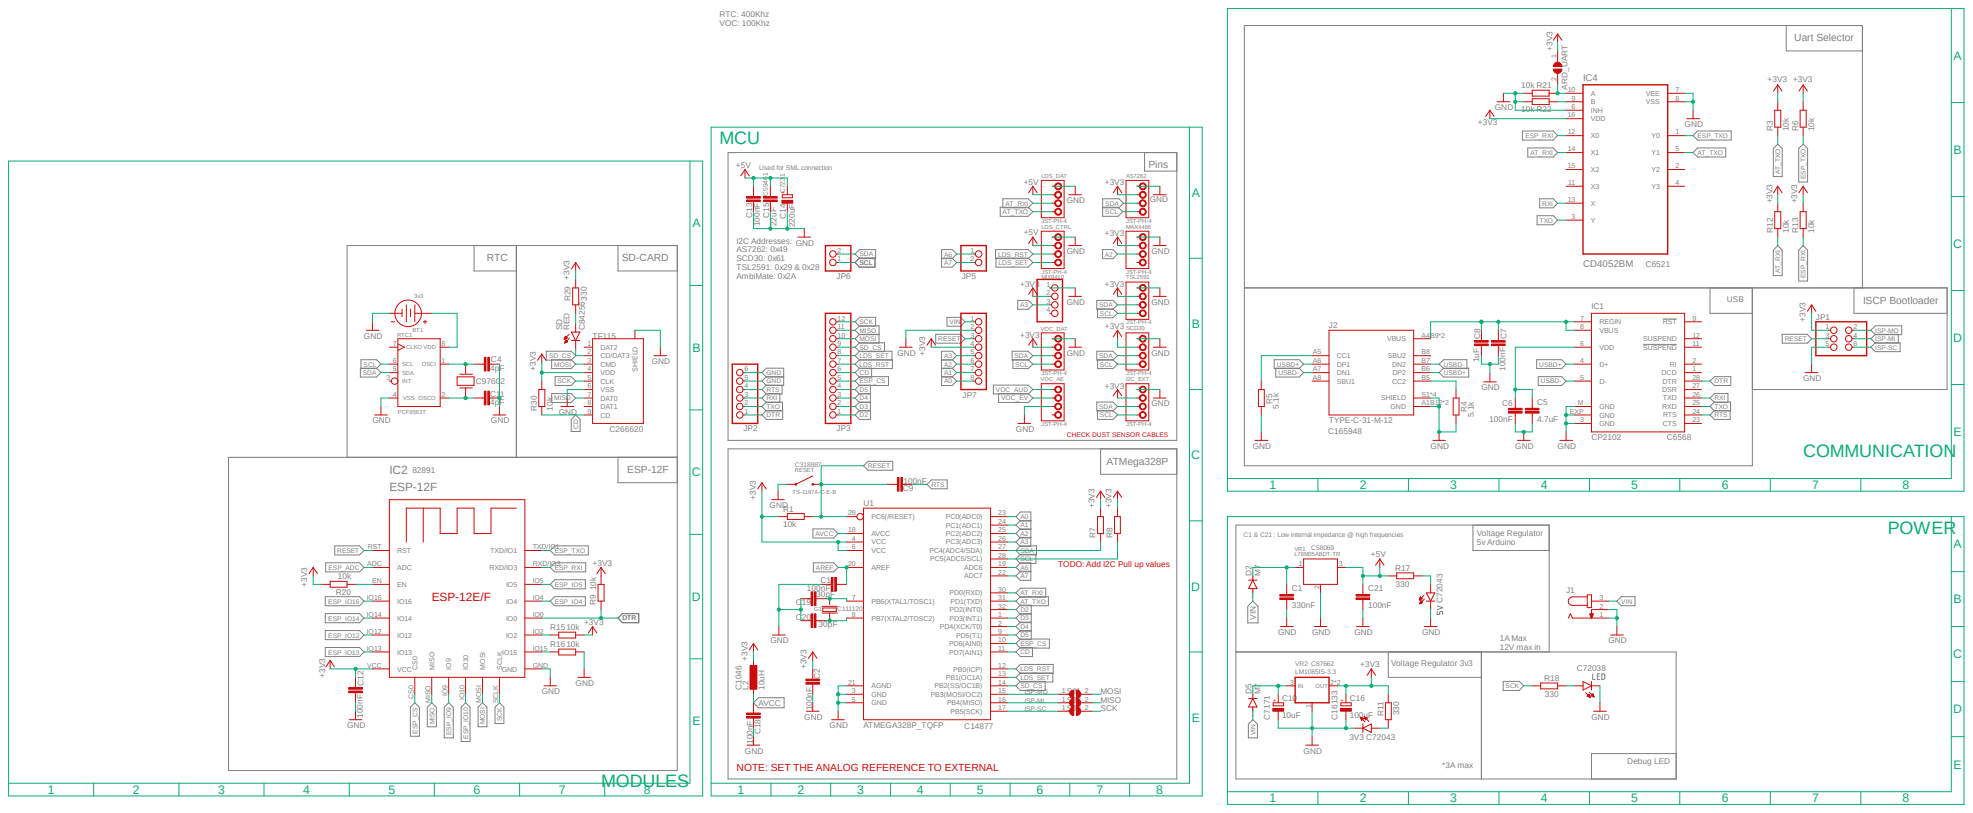
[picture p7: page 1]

Used for SML connection RTC: 400Khz VOC: 100Khz

SCK
RTS RTS RTS CD

CHECK DUST SENSOR CABLES

ESP-12F

TODO: Add I2C Pull up values

SpiceOrder 1 SpiceOrder 2

NOTE: SET THE ANALOG REFERENCE TO EXTERNAL

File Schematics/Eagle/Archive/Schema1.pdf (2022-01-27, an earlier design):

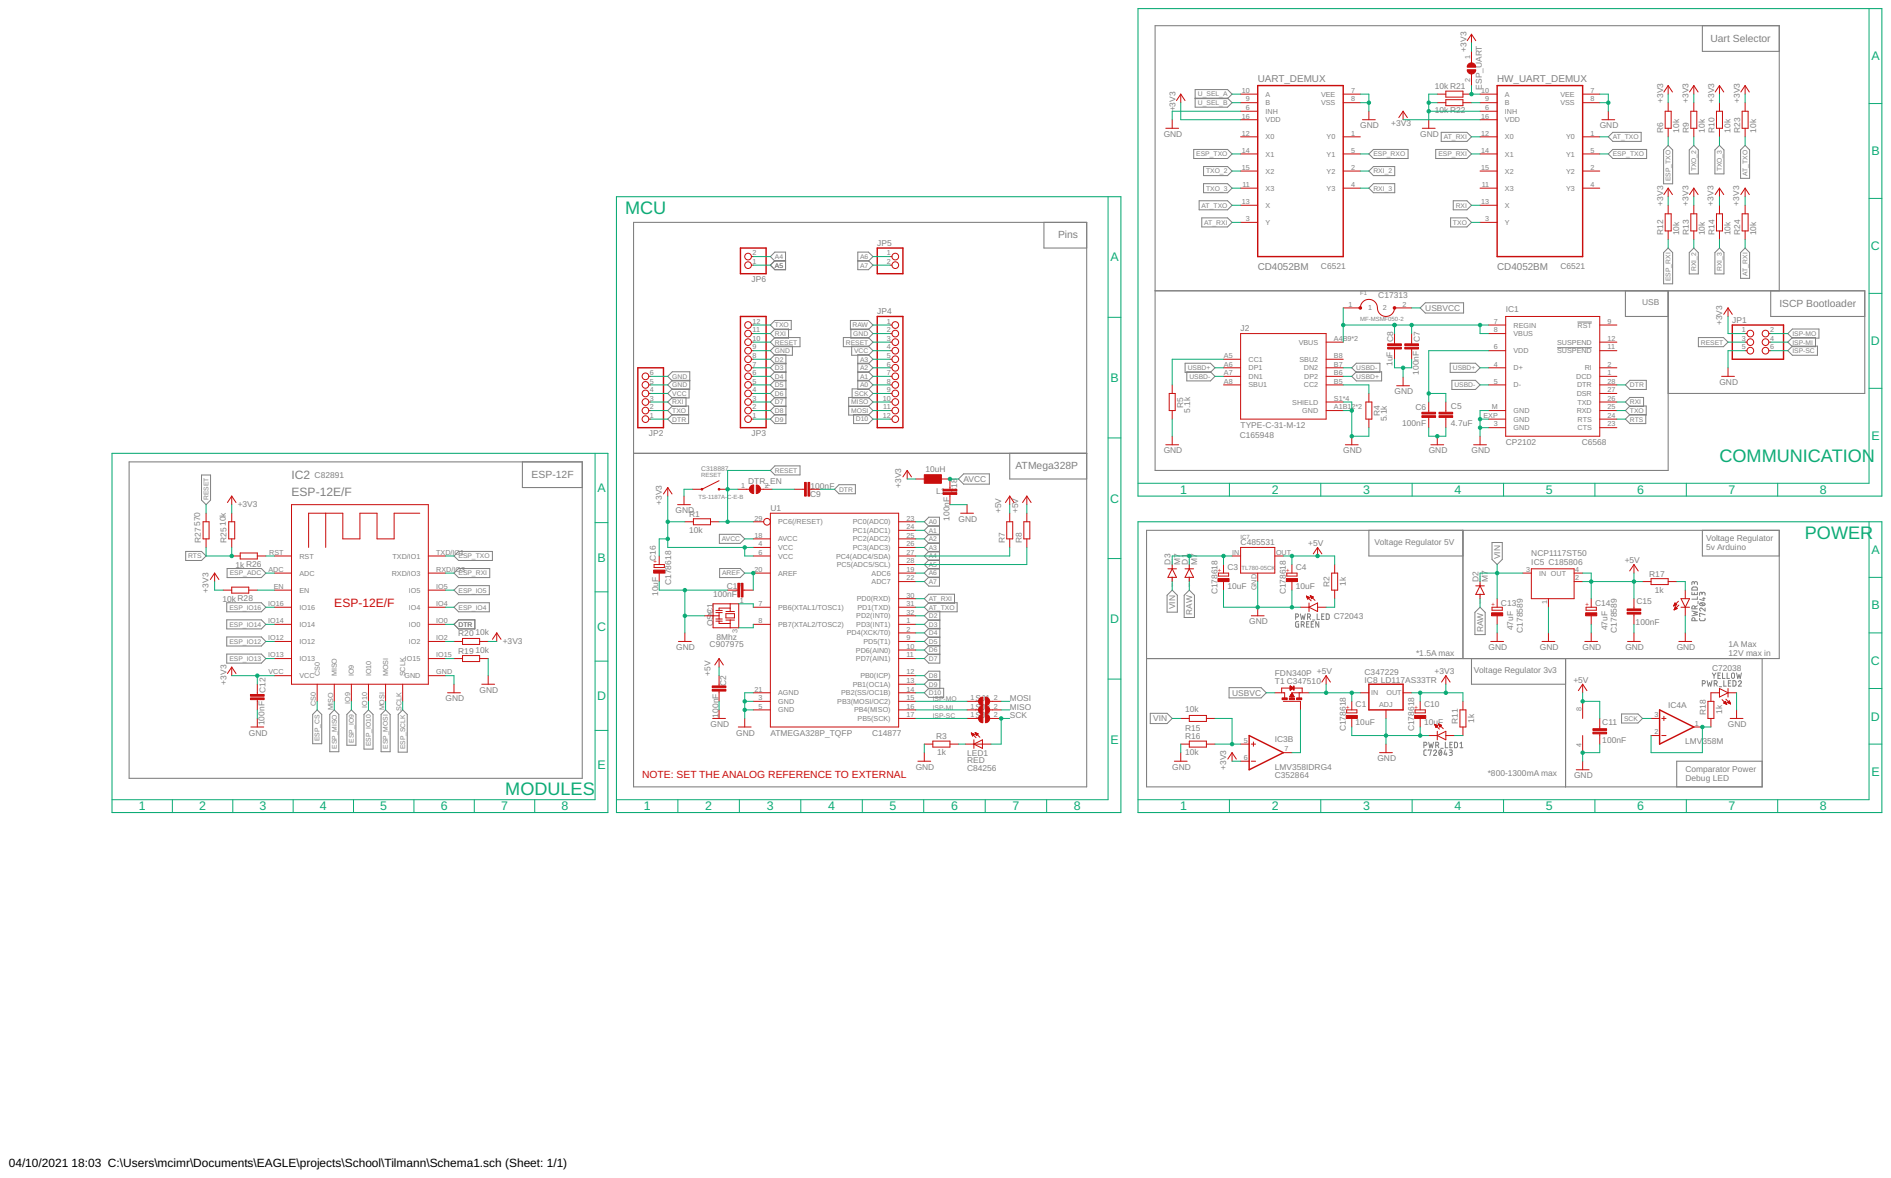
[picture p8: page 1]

ESP-12F

NOTE: SET THE ANALOG REFERENCE TO EXTERNAL

Comparator Power Debug LED

04/10/2021 18:03 C:\Users\mcimr\Documents\EAGLE\projects\School\Tilmann\Schema1.sch (Sheet: 1/1)

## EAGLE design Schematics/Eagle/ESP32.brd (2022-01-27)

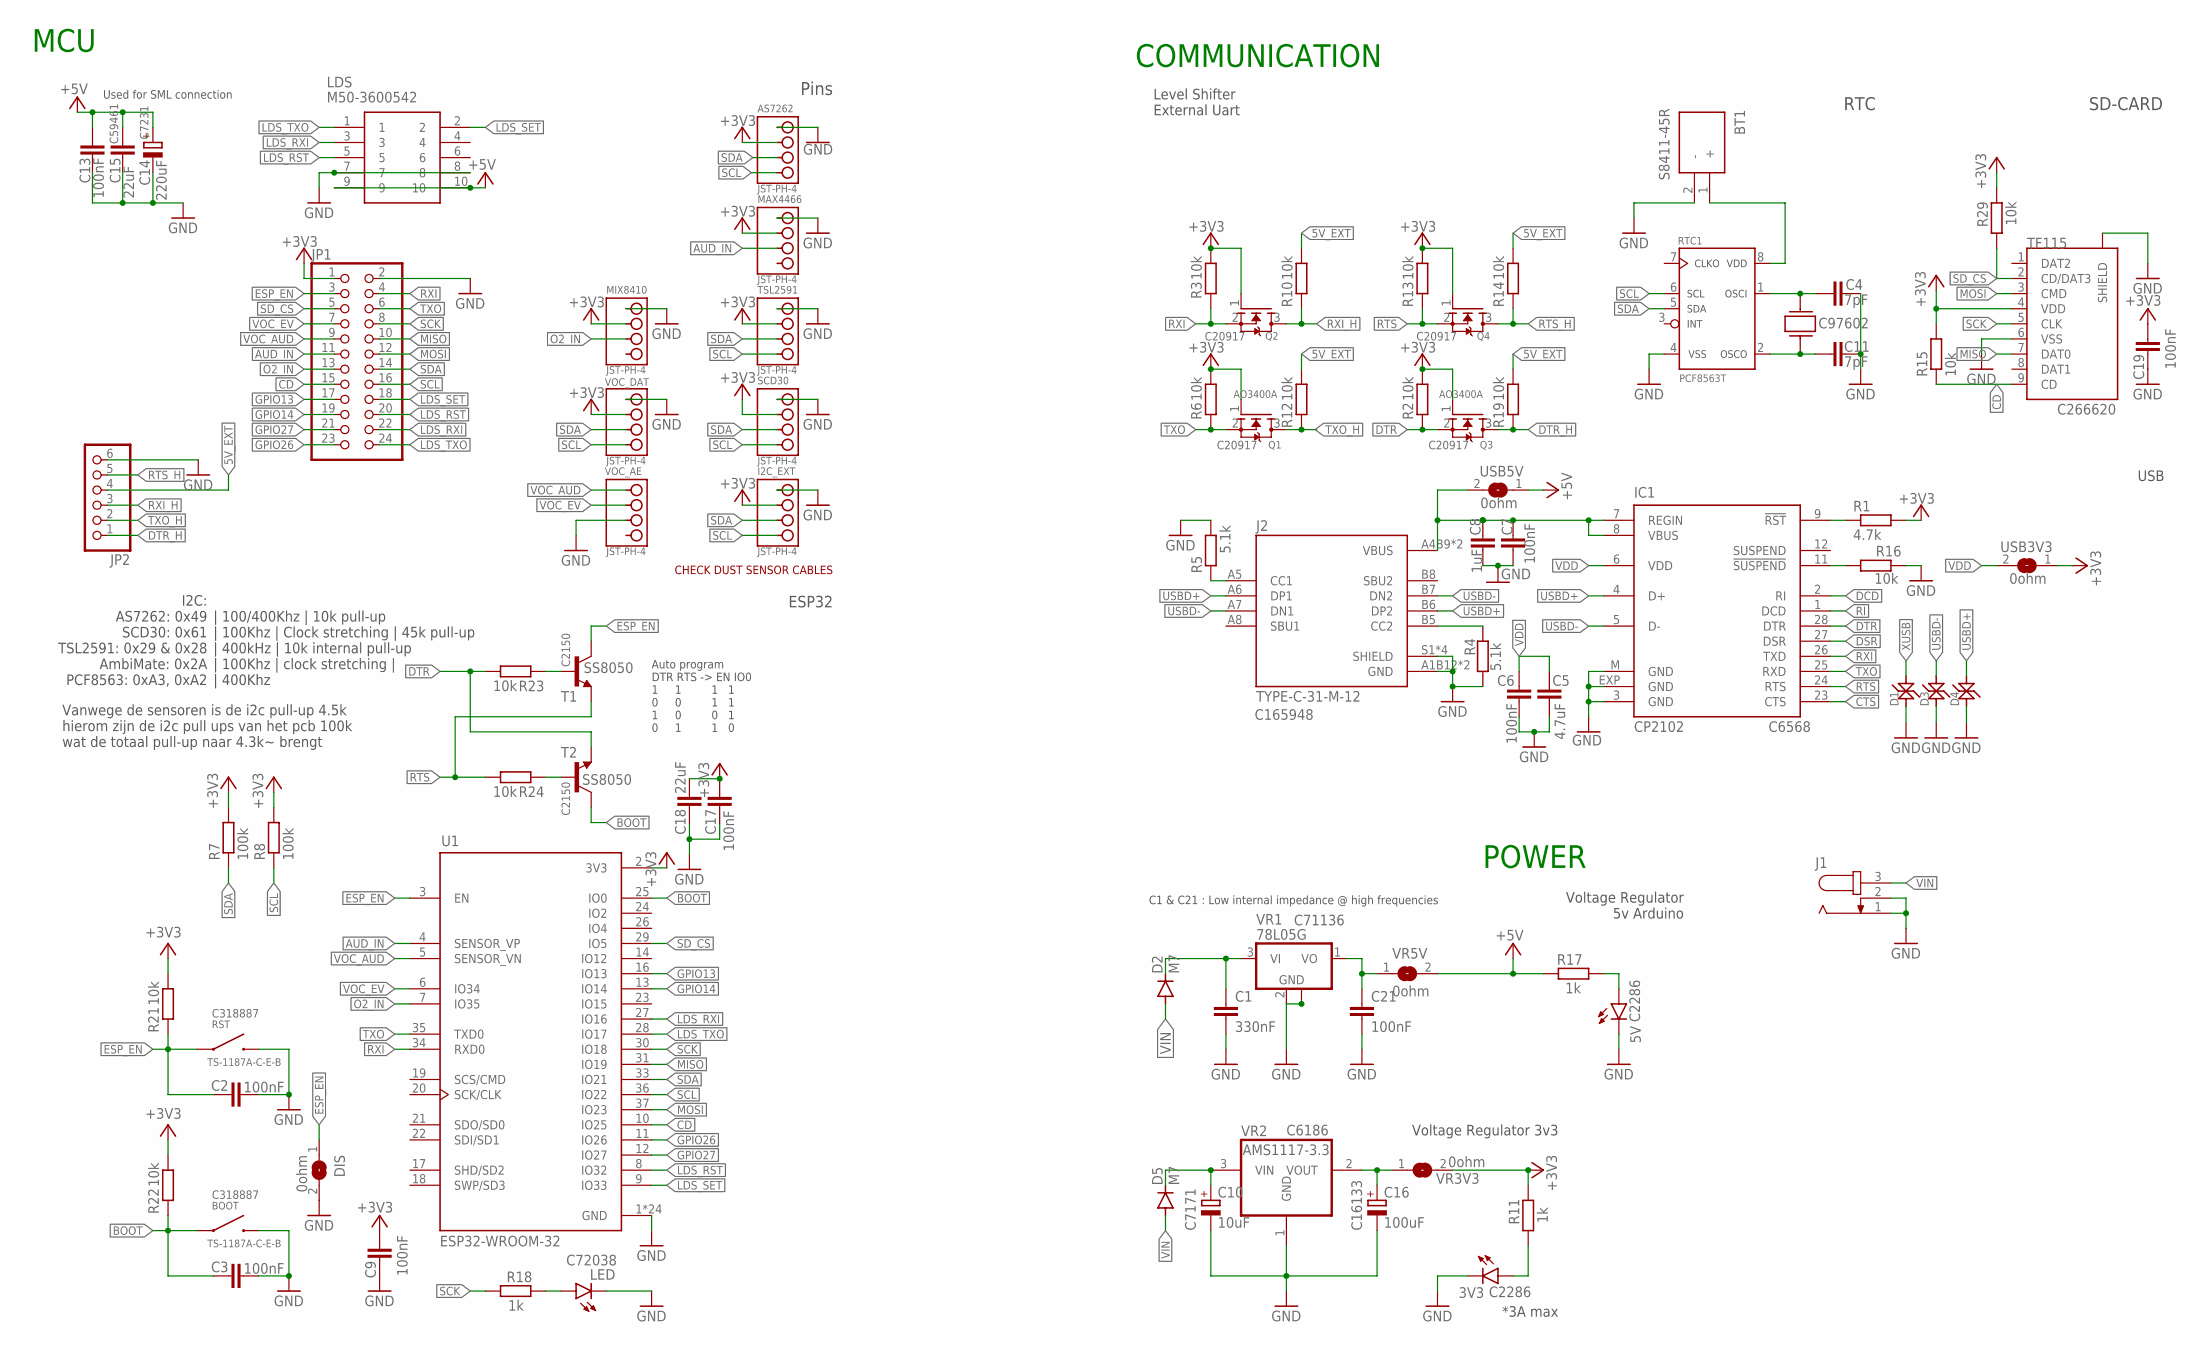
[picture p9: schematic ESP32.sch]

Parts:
3V3, 5V: C2286; CHIPLED_0603
AS7262: JST-PH-4
BOOT: TS-1187A-C-E-B
BT1: S8411-45R; S8411-45R_1
C1: 330nF; C0805
C2, C3, C6, C7, C9, C13, C17, C19, C21: 100nF; C0402
C4, C11: 7pF; C0402
C5: 4.7uF; C0402
C8: 1uF; C0402
C10: 10uF; A/3216-18R
C14: 220uF; D/7343-31R
C15, C18: 22uF; C0603
C16: 100uF; B/3528-21W
D1, D3, D4: LESD5D5.0CT1G
D2, D5: M7; DO-214AC
DIS: 0ohm; SJ
G1: 32.768KHZ
I2C_EXT: JST-PH-4
IC1: CP2102; MLP28
J1: JACK-PLUG1; SPC4078
J2: TYPE-C-31-M-12; HRO_TYPE-C-31-M-12
JP1: PINHD-2X12; 2X12
JP2: PINHD-1X6/90; 1X06/90
LDS: M50-3600542; M503600542
LED: YELLOW; CHIPLED_0603
MAX4466: JST-PH-4
MIX8410: JST-PH-4
Q1, Q2, Q3, Q4: AO3400A; SOT23
R1: 4.7k; R0402
R2, R3, R6, R10, R12, R13, R14, R15, R16, R19, R21, R22, R23, R24, R29: 10k; R0402
R4, R5: 5.1k; R0402
R7, R8: 100k; R0402
R11, R17, R18: 1k; R0805
RST: TS-1187A-C-E-B
RTC1: PCF8563T; SOIC8
SCD30: JST-PH-4
T1, T2: SS8050; SOT23-BEC
TF115: TF-115
TSL2591: JST-PH-4
U1: ESP32-WROOM-32; MODULE_ESP32-WROOM-32
USB3V3, USB5V: 0ohm; SJ
VOC_AE: JST-PH-4
VOC_DAT: JST-PH-4
VR1: 78L05G; SOT89
VR2: AMS1117-3.3; SOT223
VR3V3, VR5V: 0ohm; SJ

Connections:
5V_EXT: JP2.4, R10.1, R12.1, R14.1, R19.1
+3V3: AS7262.P2 (2), C9.2, C17.2, C18.2, C19.2, I2C_EXT.P2 (2), JP1.1, MAX4466.P2 (2), MIX8410.P2 (2), Q1.1 (G), Q2.1 (G), Q3.1 (G), Q4.1 (G), R1.2, R2.1, R3.1, R6.1, R7.2, R8.2, R11.2, R13.1, R15.2, R21.1, R22.1, R29.2, SCD30.P2 (2), TF115.4 (VDD), TSL2591.P2 (2), U1.2 (3V3), USB3V3.1, VOC_DAT.P2 (2), VR3V3.2
+5V: C13.1, C14.+, C15.1, LDS.9, LDS.10, R17.2, USB5V.1, VR5V.2
AUD_IN: JP1.11, MAX4466.P3 (3), U1.4 (SENSOR_VP)
BOOT: BOOT.A, BOOT.B (A), C3.1, R22.2, T2.C, U1.25 (IO0)
CD: JP1.15, R15.1, TF115.9 (CD), U1.10 (IO25)
CTS: IC1.23 (CTS)
DCD: IC1.2 (RI)
DSR: IC1.27 (DSR)
DTR: IC1.28 (DTR), Q3.2 (S), R2.2, R23.1, T2.E
DTR_H: JP2.1, Q3.3 (D), R19.2
ESP_EN: C2.1, DIS.1, JP1.3, R21.2, RST.A, RST.B (A), T1.C, U1.3 (EN)
GND: 3V3.C, 5V.C, AS7262.P1 (1), BOOT.C, BOOT.D (C), BT1.2 (-), C1.2, C2.2, C3.2, C4.2, C5.2, C6.2, C7.2, C8.2, C9.1, C10.-, C11.2, C13.2, C14.-, C15.2, C16.-, C17.1, C18.1, C19.1, C21.2, D1.P$1, D3.P$1, D4.P$1, DIS.2, I2C_EXT.P1 (1), IC1.3 (GND), IC1.EXP (GND), IC1.M (GND), J1.1, J1.2, J2.A1B12 (GND), J2.B1A12 (GND), J2.S1 (SHIELD), J2.S2 (SHIELD), J2.S3 (SHIELD), J2.S4 (SHIELD), JP1.2, JP2.6, LDS.7, LDS.8, LED.C, MAX4466.P1 (1), MIX8410.P1 (1), R4.2, R5.2, R16.1, RST.C, RST.D (C), RTC1.4 (VSS), SCD30.P1 (1), TF115.6 (VSS), TF115.10 (SHIELD), TF115.11 (SHIELD), TF115.12 (SHIELD), TF115.13 (SHIELD), TSL2591.P1 (1), U1.1 (GND), U1.15 (GND), U1.38 (GND), U1.39_1 (GND), U1.39_2 (GND), U1.39_3 (GND), U1.39_4 (GND), U1.39_5 (GND), U1.39_6 (GND), U1.39_7 (GND), U1.39_8 (GND), U1.39_9 (GND), U1.39_10 (GND), U1.39_11 (GND), U1.39_12 (GND), U1.39_13 (GND), U1.39_14 (GND), U1.39_15 (GND), U1.39_16 (GND), U1.39_17 (GND), U1.39_18 (GND), U1.39_19 (GND), U1.39_20 (GND), U1.39_21 (GND), VOC_AE.P3 (3), VOC_DAT.P1 (1), VR1.2 (GND), VR1.2@1 (GND), VR2.1 (GND)
GPIO13: JP1.17, U1.16 (IO13)
GPIO14: JP1.19, U1.13 (IO14)
GPIO26: JP1.23, U1.11 (IO26)
GPIO27: JP1.21, U1.12 (IO27)
LDS_RST: JP1.20, LDS.5, U1.8 (IO32)
LDS_RXI: JP1.22, LDS.3, U1.27 (IO16)
LDS_SET: JP1.18, LDS.2, U1.9 (IO33)
LDS_TXO: JP1.24, LDS.1, U1.28 (IO17)
MISO: JP1.10, TF115.7 (DAT0), U1.31 (IO19)
MOSI: JP1.12, TF115.3 (CMD), U1.37 (IO23)
unnamed: C4.1, G1.2, RTC1.1 (OSCI)
unnamed: R23.2, T1.B
unnamed: BT1.1 (+), RTC1.8 (VDD)
unnamed: 3V3.A, R11.1
unnamed: IC1.9 (!RST), R1.1
unnamed: C11.1, G1.1, RTC1.2 (OSCO)
unnamed: C1.1, D2.C, VR1.3 (VI)
unnamed: LED.A, R18.2
unnamed: R24.2, T2.B
unnamed: J2.B5 (CC2), R4.1
unnamed: J2.A5 (CC1), R5.1
unnamed: IC1.11 (!SUSPEND), R16.2
unnamed: C21.1, VR1.1 (VO), VR5V.1
unnamed: C16.+, VR2.2 (VOUT), VR3V3.1
unnamed: 5V.A, R17.1
unnamed: C10.+, D5.C, VR2.3 (VIN)
O2_IN: JP1.13, MIX8410.P3 (3), U1.7 (IO35)
RI: IC1.1 (DCD)
RTS: IC1.24 (RTS), Q4.2 (S), R13.2, R24.1, T1.E
RTS_H: JP2.5, Q4.3 (D), R14.2
RXI: IC1.26 (TXD), JP1.4, Q2.2 (S), R3.2, U1.34 (RXD0)
RXI_H: JP2.3, Q2.3 (D), R10.2
SCK: JP1.8, R18.1, TF115.5 (CLK), U1.30 (IO18)
SCL: AS7262.P4 (4), I2C_EXT.P4 (4), JP1.16, R8.1, RTC1.6 (SCL), SCD30.P4 (4), TSL2591.P4 (4), U1.36 (IO22), VOC_DAT.P4 (4)
SDA: AS7262.P3 (3), I2C_EXT.P3 (3), JP1.14, R7.1, RTC1.5 (SDA), SCD30.P3 (3), TSL2591.P3 (3), U1.33 (IO21), VOC_DAT.P3 (3)
SD_CS: JP1.5, R29.1, TF115.2 (CD/DAT3), U1.29 (IO5)
TXO: IC1.25 (RXD), JP1.6, Q1.2 (S), R6.2, U1.35 (TXD0)
TXO_H: JP2.2, Q1.3 (D), R12.2
USBD+: D4.P$2, IC1.4 (D+), J2.A6 (DP1), J2.B6 (DP2)
USBD-: D3.P$2, IC1.5 (D-), J2.A7 (DN1), J2.B7 (DN2)
VDD: C5.1, C6.1, IC1.6 (VDD), USB3V3.2
VIN: D2.A, D5.A, J1.3
VOC_AUD: JP1.9, U1.5 (SENSOR_VN), VOC_AE.P1 (1)
VOC_EV: JP1.7, U1.6 (IO34), VOC_AE.P2 (2)
XUSB: C7.1, C8.1, D1.P$2, IC1.7 (REGIN), IC1.8 (VBUS), J2.A4B9 (VBUS), J2.B4A9 (VBUS), USB5V.2

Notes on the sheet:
USB
Pins
Voltage Regulator 3v3
*3A max
Voltage Regulator 5v Arduino
POWER
COMMUNICATION
MCU
CHECK DUST SENSOR CABLES
RTC
SD-CARD
I2C: AS7262: 0x49 SCD30: 0x61 TSL2591: 0x29 & 0x28 AmbiMate: 0x2A PCF8563: 0xA3, 0xA2
C1 & C21 : Low internal impedance @ high frequencies
Used for SML connection
| 100/400Khz | 10k pull-up | 100Khz | Clock stretching | 45k pull-up | 400kHz | 10k internal pull-up | 100Khz | clock stretching | | 400Khz
Auto program DTR RTS -> EN IO0 1 1 1 1 0 0 1 1 1 0 0 1 0 1 1 0
Level Shifter External Uart
ESP32
Vanwege de sensoren is de i2c pull-up 4.5k hierom zijn de i2c pull ups van het pcb 100k wat de totaal pull-up naar 4.3k~ brengt

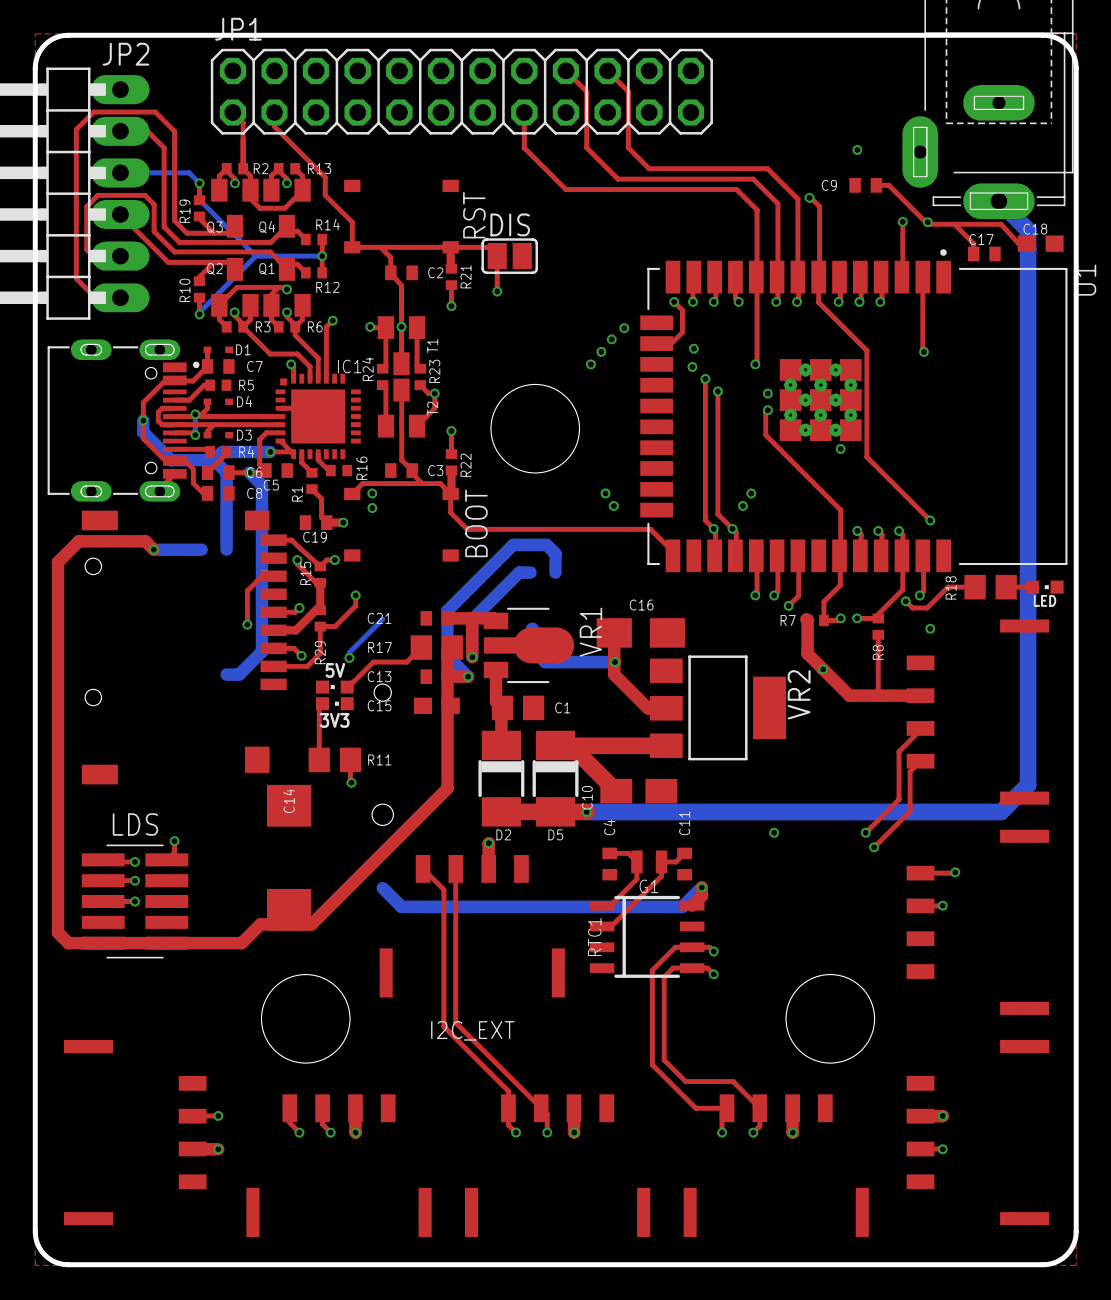
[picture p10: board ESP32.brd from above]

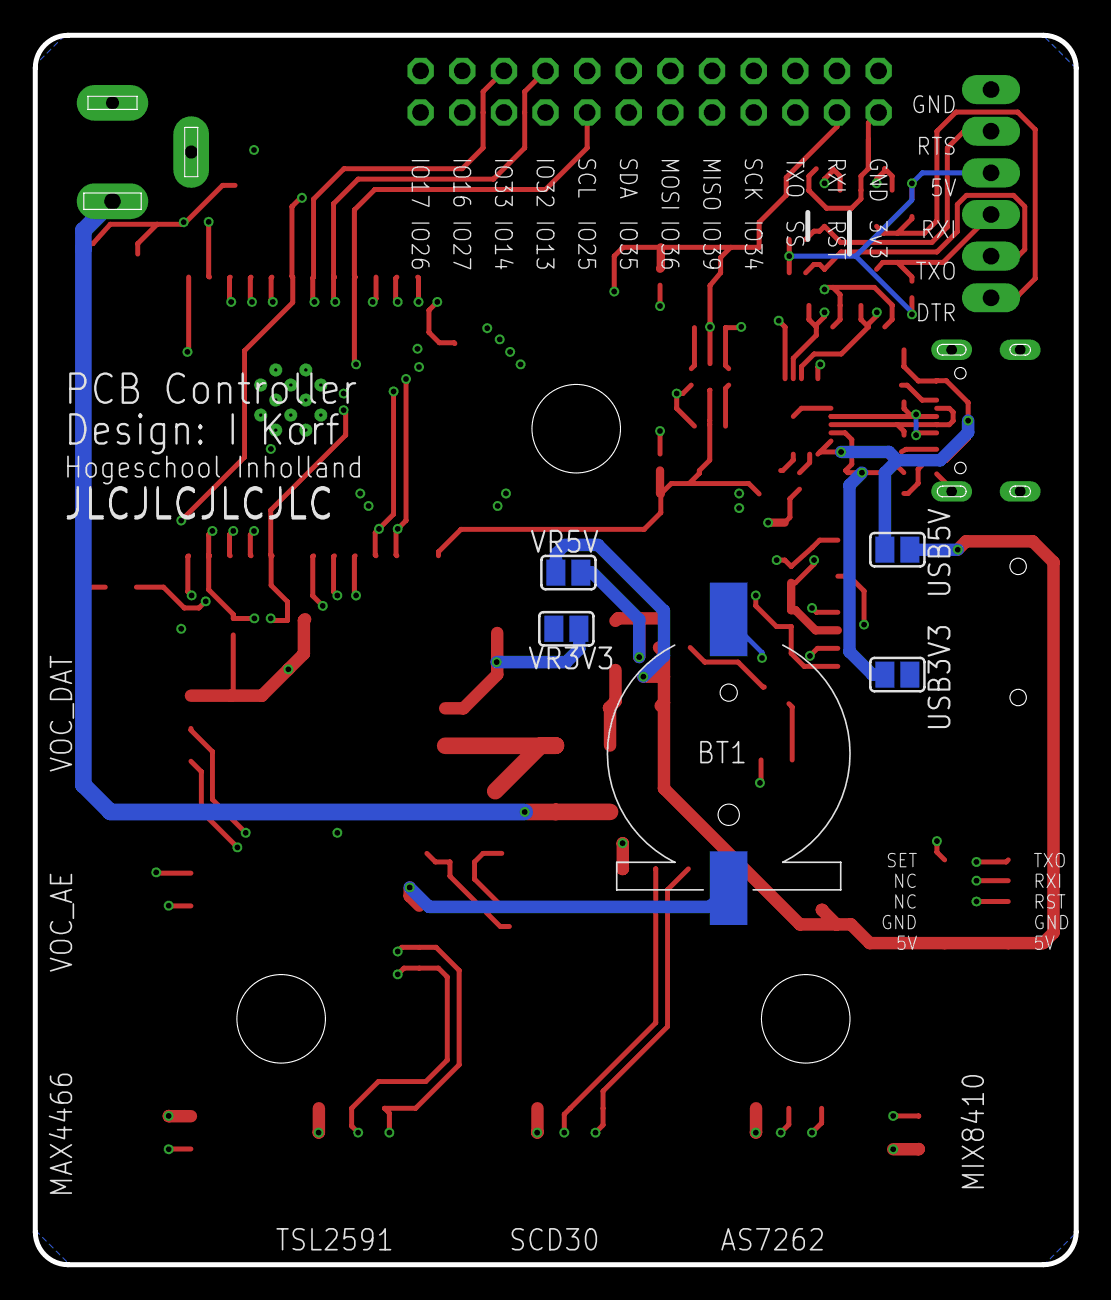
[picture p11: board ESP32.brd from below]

Board: 4 copper layers, 63.5 x 75.0 mm, 84 parts (5 on the bottom side), 54 nets.

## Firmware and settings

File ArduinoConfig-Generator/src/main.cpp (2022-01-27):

#include <iostream>
#include <fstream>
#include <sstream>
#include <algorithm>
#include <conio.h>
#include <stdlib.h>
#include <cctype>
#include <string>

#define KEY 4181456146874

struct WifiSettings {
	std::string asset_id;
	std::string mqtt_username;
	std::string mqtt_password;
	std::string client_id;
	uint16_t mqtt_port;
	union {
		uint8_t IParr[4];
		struct {
			uint8_t IP_byte1;
			uint8_t IP_byte2;
			uint8_t IP_byte3;
			uint8_t IP_byte4;
		};
	};
	std::string SSID;
	std::string Network_password;
	// newvariable
};

bool getWifiConfig(WifiSettings& WFS);
bool checkUserInput(std::string input, bool recursive = false);

int main(){
	// allocate the WFS.
	WifiSettings WFS;
	while(!getWifiConfig(WFS));

	/*
	WFS.asset_id = "/6s1BZTA6OQN21yzYjEcHV6";
	WFS.mqtt_username = "alkmaar:mqtt_sensbox";
	WFS.mqtt_password = "55c151c7-67dd-4533-8c4e-3bdbf0e84129";
	WFS.client_id = "SenseBox_test";
	WFS.mqtt_port = 8883;
	WFS.IParr[0] = 51;
	WFS.IParr[1] = 144;
	WFS.IParr[2] = 101;
	WFS.IParr[3] = 191;
	WFS.SSID = "SSID";
	WFS.Network_password = "PASSWORD";
	*/

	std::ofstream output;
	output.open("MQTTSettings.dat", std::fstream::binary);

	std::stringstream output_stream;

	output_stream << WFS.asset_id << std::endl;
	output_stream << WFS.mqtt_username << std::endl;
	output_stream << WFS.mqtt_password << std::endl;
	output_stream << WFS.client_id << std::endl;
	output_stream << WFS.mqtt_port << std::endl;
	output_stream << (int)WFS.IParr[0] << "." << (int)WFS.IParr[1] << "." << (int)WFS.IParr[2] << "." << (int)WFS.IParr[3] << std::endl;
	output_stream << WFS.SSID << std::endl;
	output_stream << WFS.Network_password << std::endl;
	// new variable EXAMPLE:
	// output_stream << WFS.newvariable << std::endl;



	// perform encryption
	size_t stringlength = output_stream.str().length();
	for (size_t i = 0; i < stringlength; i++)
	{	
		char convert = output_stream.str()[i];
		uint8_t crypt = (static_cast<size_t>(convert) + i + (KEY % 255) + stringlength) % 255;
		uint8_t mult = (static_cast<size_t>(convert) + i + (KEY % 255) + stringlength) / 255;
		uint16_t val = mult << 8 | crypt;
		
		output.write((char*)&val, sizeof(uint16_t));
	}
	// signify end of file.
	char eof = 0x05;
	output.write(&eof, sizeof(char));

	output.close();

	std::cout << std::endl;

	return 0;
}


bool getWifiConfig(WifiSettings& WFS){
	bool valid = true;
	// asset id //
	do{
		std::cout << "Please provide the asset id for the SenseBox." << std::endl;
		std::cout << "asset_id: /"; std::cin >> WFS.asset_id; std::cout<< std::endl;
		WFS.asset_id.insert(WFS.asset_id.begin(), '/');
	}while(!checkUserInput(WFS.asset_id));
	// mqtt username //
	do{
		std::cout << "Please provide the mqtt username for the SenseBox. [location:name]" << std::endl;
		std::cout << "mqtt username: "; std::cin >> WFS.mqtt_username; std::cout<< std::endl;
	}while(!checkUserInput("" + WFS.mqtt_username));
	// mqtt password // 
	do{
		std::cout << "Please provide the mqtt_password for the SenseBox." << std::endl;
		std::cout << "mqtt password: "; std::cin >> WFS.mqtt_password; std::cout<< std::endl;
	}while(!checkUserInput("" + WFS.mqtt_password));
	// client id //
	do{
		std::cout << "Please provide the client id for the SenseBox." << std::endl;
		std::cout << "client id: "; std::cin >> WFS.client_id; std::cout<< std::endl;
	}while(!checkUserInput("" + WFS.client_id));
	// MQTT port //
	std::string port;
	do{
		valid = true;
		std::cout << "Please provide the mqtt port for the SenseBox. [integer]" << std::endl;
		std::cout << "mqtt port: "; std::cin >> port; std::cout<< std::endl;
		try{
			for(std::size_t i = 0; i < port.length(); i++){
				if(!isdigit(port[i])){
					throw std::invalid_argument("");
				}
			}
			WFS.mqtt_port = std::atoi(port.c_str());
		}
		catch(std::invalid_argument const& ex){
			std::cout << "Input should be an integer." << std::endl;
			valid = false;
			continue; // skip the check userinput part.
		}
	}while(!valid || !checkUserInput("" + std::to_string(WFS.mqtt_port)));
	// SSID //
	do{
		std::cout << "Please provide the SSID of the network the sensebox should connect to." << std::endl;
		std::cout << "SSID: "; std::cin >> WFS.SSID; std::cout<< std::endl;
	}while(!checkUserInput("" + WFS.SSID));
	// network password //
	do{
		valid = true;
		std::cout << "Please provide the password of the network the sensebox should connect to." << std::endl;
		std::cout << "password: "; 
		std::string password;
		int key = 0;
		while(key!=13 )  // Enter 
		{
			key = getch();
			if(key == 8 ){ // Backspace
				password.erase(password.end()-1);
			}
			// check if key is valid ASCII
			else if(key >= 0x20 && key <= 0x7E){
				password += key;
			}
		}
		std::cout << std::endl << "re-enter password: "; 
		std::string password2;
		key = 0;
		while(key!=13 )  // Enter
		{
			key = getch();
			if(key == 8 ){  // Backspace
				password2.erase(password2.end()-1);
			}
			// check if key is valid ASCII
			else if(key >= 0x20 && key <= 0x7E){
				password2 += key;
			}
		}
		if(password2.compare(password)){
			std::cout << "password mismatch. " << std::endl;
			valid = false;
		}
		else{
			WFS.Network_password = password;
		}
		std::cout << std::endl;
	}while(!valid);
	// mqtt broker ip //
	std::string IP;
	std::string IPcopy;
	do{
		valid = true;
		std::cout << "Please provide the mqtt broker ip for the SenseBox. [ip1.ip2.ip3.ip4]" << std::endl;
		std::cout << "mqtt broker ip: "; std::cin >> IP; std::cout<< std::endl;
		IPcopy = IP;
		size_t n = std::count(IP.begin(), IP.end(), '.'); // get occurrence count of .
		// check if 3 seperators are provided. 
		if(n == 3){
			int i = 3;
			while(i > 0 && valid){
				std::size_t found = IP.rfind("."); // find last . and get substring
				if(found !=std::string::npos){
					std::string byte = IP.substr(found + 1);
					try{
						for(std::size_t i = 0; i < byte.length(); i++){
							if(!isdigit(byte[i])){
								throw std::invalid_argument("");
							}
						}
						WFS.IParr[i] = std::stoi(byte);
					}
					catch(std::invalid_argument const& ex){
						std::cout << "Input should be an integer." << std::endl;
						valid = false;
						continue; // skip the check userinput part.
					}
					IP = IP.substr(0, found);
					i--;
				}
			}
			if(!valid){
				continue;
			}
			try{
				WFS.IParr[i] = std::stoi(IP);
			}
			catch(std::invalid_argument const& ex){
				std::cout << "Input should be an integer." << std::endl;
				valid = false;
				continue; // skip the check userinput part.
			}			
		}
		else{
			std::cout << "invalid ip address. " << std::endl;
			valid = false;
			continue; // skip the check userinput part.
		}
	}while(!valid || !checkUserInput("" + IPcopy));

	// example new variable setting
	/*
	do{
		// get user input
		// assign to a variable
		// if need be the "valid" variable can be used to add more security ( see MQTT port for an example )
	}while(!checkUserInput("" + string));
	*/

	return true;
}

bool checkUserInput(std::string input, bool recursive){
	if(!recursive){
		std::cout << "You entered: " << input << std::endl;
	}
	std::string confirm;
	std::cout << "Is this correct? [y\\n] "; 
	int key = getch();
	std::cout << std::endl;
	if(key == 'y' || key == 13 /* Enter */){
		return true;
	}
	else if(key == 'n'){
		return false;
	}
	else{
		std::cout << "please provide a \"y\" or an \"n\"." << std::endl;
		// yay recursive
		return checkUserInput(input, true);
	}
	
}

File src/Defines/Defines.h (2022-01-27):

/**
 * @file Defines.h
 * @author Imre Korf
 * @brief Defines file used for global precompile settings
 * @version 0.1
 * @date 2021-11-29
 * 
 * @copyright Copyright (c) 2021
 * 
 */
#pragma once

/**
 * @defgroup DEFINES Global defines
 * This list contains values of different definitions used throughout the project. 
 * @{
 */

/**
 * @brief Version of the Sensebox software
 * A change in the first  version indicator is a major version change which might not be compatible with older major versions
 * A change in the second version indicator is a minor version change which should be compatible with other of the same major versions
 * A change in the third  version indicator is a tweak version change, this will include mostly small bug fixes  
 */
#define SenseBox_VERSION "1.0.1"

/**
 * Controls the baudrate of the serial port connected to the USB port.
 */
#define BAUDRATE 115200

/** 
 * @brief Used by the source code to indicate what to debug to serial monitor
 * Value | Description
 * :-------:|:-----------------------------:
 *  0 | Print nothing to serial
 *  1 | Print errors to serial
 *  2 | Print errors and warnings to serial
 *  3 | Print errors, warnings & info to serial
 * 	4 | Print errors, warnings, info & data-dumps to serial
 *  5 | Print errors, warnings, info, data-dumps & SD-info to Serial
 */
#define DEBUGLEVEL 3
/**
 * @brief Used by the source code to indicate what to log to the SD card
 * 
 * Value | Description
 * :-------:|:-----------------------------:
 *  0 | Log nothing
 *  1 | Logs only errors
 *  2 | Logs errors & warnings
 *  3 | Logs errors, warnings & info
 *  4 | Logs errors, warnings, info & data-dumps
 */
#define LOGLEVEL 3

/**
 * @brief The amount of retries the ESP32 will try to connect to the provided WiFi network before timing out.
 */
#define WIFI_TIMEOUT 50
/**
 * @brief The amount of retries the ESP32 will try to connect to the MQTT Broker before timing out.
 */
#define MQTT_CONN_TIMEOUT 20

/** @} */


/**
 * @addtogroup ENUM
 * This list details the global enumerations used in the project.
 * @{
 */

/**  List of function return errors
 */
enum ERR_Type {
	//==== Successful exits ====//

	/** SUCCESS, No error occured. */
	SUCCESS = 0,
	/** READ_SUCCESS, A read operation was succesfull. */
	READ_SUCCESS = 0,
	/** ALREADY_INITIALIZED, Module's init function was called multiple times. */
	ALREADY_INITIALIZED = 0,

	//==== Errors ====//

	/** ERROR, generic error */
	ERROR = 1,
	/** READ_ERROR, A generic read error */
	READ_ERROR = 1,
	/** READ_FAIL, A read operation failed. */
	READ_FAIL = 1,
	/** NOT_INITIALIZED, Indicates that the module has not been initialized correctly. */
	NOT_INITIALIZED,

	// Logger Errors
	/** SD_NOT_INIT, indicates that the SD has not been properly initialized. */
	SD_NOT_INIT,

	// SBOX Errors
	/** MOD_INIT_ERR, indicates that a module was not succesfully initialized. */
	MOD_INIT_ERR,

	// RTC Errors
	/** RTC_BEGIN_ERR, indicates that the .begin() method has failed. */
	RTC_BEGIN_ERR,

	// SD Errors
	/** SD_BEGIN_ERR, indicates that the .begin() method has failed. */
	SD_BEGIN_ERR,
	/** NO_SD_CARD, indicates that no SD card was inserted. */
	NO_SD_CARD,
	/** SD_CARDTYPE_NONE, indicates that the inserted SD card type is not supported. */
	SD_CARDTYPE_NONE,
	/** SD_DIR_OPEN_FAIL, failed to open given directory. */
	SD_DIR_OPEN_FAIL,
	/** SD_NOT_A_DIR, given directory does not exist */
	SD_NOT_A_DIR,
	/** SD_MKDIR_FAIL, failed to create given directory */
	SD_MKDIR_FAIL,
	/** SD_RMDIR_FAIL, failed to remove given directory */
	SD_RMDIR_FAIL,
	/** SD_FILE_OPEN_FAIL, failed to open given file */
	SD_FILE_OPEN_FAIL,
	/** SD_WRITE_FAIL, failed to write message to file */
	SD_WRITE_FAIL,
	/** SD_APP_FAIL, failed to append message to file */
	SD_APP_FAIL,
	/** SD_RENAME_FAIL, failed to rename file */
	SD_RENAME_FAIL,
	/** SD_RM_FAIL, failed to remove file */
	SD_RM_FAIL,

	// Wifi & MQTT Errors
	/** WIFI_CONN_FAIL, failed to connect to wifi network */
	WIFI_CONN_FAIL,
	/** MQTT_CONN_FAIL, failed to connect to MQTT broker */
	MQTT_CONN_FAIL,
	/** WIFI_SETTINGS_EMPTY, provided settings file path is either invalid or file is empty */
	WIFI_SETTINGS_EMPTY,
	/** WIFI_SETTINGS_NOT_COMPLETE, provided settings file does not contain all settings */
	WIFI_SETTINGS_NOT_COMPLETE,
	/** WIFI_SETTINGS_NOT_COMPLETE, provided setting was over 50 characters */
	WIFI_SETTINGS_STRING_OVERLOAD,

	// Ambimate Errors
	/** AMBI_I2C_INIT_ERR, Aindicates that an I2C error occured in the init function. */
	AMBI_I2C_INIT_ERR,
	
	// AS7226X Errors
	/** AS726X_BEGIN_ERR, indicates that the .begin() method has failed. */
	AS726X_BEGIN_ERR,
	/** AS726X_DATA_NOT_READY, indicates that a ready was attempted but data was not yet ready */
	AS726X_DATA_NOT_READY,

	// LDS Errors
	/** NO_LDS_SENSOR, indicates that no LDS sensor was found. */
	NO_LDS_SENSOR,

	// SCD30 Errors
	/** SCD30_BEGIN_ERR, indicates that the .begin() method has failed. */
	SCD30_BEGIN_ERR,
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

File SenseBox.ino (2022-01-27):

/**
 * @file SenseBox.ino
 * @author Imre Korf
 * @brief Main sketch file for the IoT minor
 * @version 0.1
 * @date 2021-11-23
 * 
 * @copyright Copyright (c) 2021
 * 
 */

// TODO: what to do when SD card is unplugged? implement errors
// TODO: weird bug with the hour value increasing with 40 when the second value is above 39.
// TODO: implement only storing 10 log files
// TODO: fix bug with the rtc giving wrong day values
// TODO: fix ambimate reading 0's the first time. Also fix ambimate event reading.
// TODO: implement all the other things
// TODO: fix AS7262 color sensor updating values :)


#include "src/MQTT/MQTT.h"
//#include "src/Sbox/Sbox.h"
#include "src/Logger/Logger.h"

//SBox Sbox;
MQTTClient M_Client;


void setup(){
  pinMode(18, OUTPUT);
	if(Logger::getInstance().init()){
    while(1);
	}
	//Sbox.init();  
	// MQTT INIT
	M_Client.init("/MQTTSettings.dat");  
}

//ColorSpectrum CS;
//PM25_AQI_Data DUST;

void loop(){
/*
  //
  //digitalWrite(18, HIGH);   // turn the LED on (HIGH is the voltage level)
  //delay(1000);                       // wait for a second
  //Logger::getInstance().println("OFF", LogLevel::Info);
  //digitalWrite(18, LOW);    // turn the LED off by making the voltage LOW
  //delay(1000);                       // wait for a second
*/
	AmbimateData A_DAT = Sbox.getAmbimateData();

	Sbox.getColorSpectrum(CS);	
	//Sbox.getLDSData(DUST);

	int audio = Sbox.getMax4466();
	float O2val = Sbox.getO2();
	SCD30_DATA SCD30_D = Sbox.getSCD30Data();
	TSL2591_DATA TSL_DAT = Sbox.getTSL2591Data();
	RTC_DATE_TIME datetime = Sbox.getTime();
	
  Logger::getInstance().println("ambimate data", LogLevel::Info);
  Logger::getInstance().print("Temperatuur: ", LogLevel::Info); Logger::getInstance().print(A_DAT.temperatureC, LogLevel::Info); Logger::getInstance().println(" C", LogLevel::Info); 
  Logger::getInstance().print("Humidity: ", LogLevel::Info); Logger::getInstance().print(A_DAT.Humidity, LogLevel::Info); Logger::getInstance().println(" RH", LogLevel::Info); 
  Logger::getInstance().print("BatVolts: ", LogLevel::Info); Logger::getInstance().print(A_DAT.batVolts, LogLevel::Info); Logger::getInstance().println(" V", LogLevel::Info); 
  Logger::getInstance().print("Audio: ", LogLevel::Info); Logger::getInstance().print(A_DAT.audio, LogLevel::Info); Logger::getInstance().println("", LogLevel::Info); 
  Logger::getInstance().print("eco2: ", LogLevel::Info); Logger::getInstance().print(A_DAT.eco2_ppm, LogLevel::Info); Logger::getInstance().println(" ppm", LogLevel::Info); 
  Logger::getInstance().print("voc: ", LogLevel::Info); Logger::getInstance().print(A_DAT.voc_ppm, LogLevel::Info); Logger::getInstance().println(" ppm", LogLevel::Info); 
  Logger::getInstance().print("motion event: ", LogLevel::Info); Logger::getInstance().print(A_DAT.MOT_EVENT, LogLevel::Info); Logger::getInstance().println("", LogLevel::Info); 
  Logger::getInstance().print("Audio event: ", LogLevel::Info); Logger::getInstance().print(A_DAT.AUD_EVENT, LogLevel::Info); Logger::getInstance().println("", LogLevel::Info); 
  Logger::getInstance().print("PIR event: ", LogLevel::Info); Logger::getInstance().print(A_DAT.PIR_EVENT, LogLevel::Info); Logger::getInstance().println("\n", LogLevel::Info); 

  Logger::getInstance().println("AS7262 data", LogLevel::Info);
  Logger::getInstance().print("Violet: ", LogLevel::Info); Logger::getInstance().print(CS.Violet, LogLevel::Info); Logger::getInstance().println("", LogLevel::Info); 
  Logger::getInstance().print("Blue: ", LogLevel::Info); Logger::getInstance().print(CS.Blue, LogLevel::Info); Logger::getInstance().println("", LogLevel::Info); 
  Logger::getInstance().print("Green: ", LogLevel::Info); Logger::getInstance().print(CS.Green, LogLevel::Info); Logger::getInstance().println("", LogLevel::Info); 
  Logger::getInstance().print("Yellow: ", LogLevel::Info); Logger::getInstance().print(CS.Yellow, LogLevel::Info); Logger::getInstance().println("", LogLevel::Info); 
  Logger::getInstance().print("Orange: ", LogLevel::Info); Logger::getInstance().print(CS.Orange, LogLevel::Info); Logger::getInstance().println("", LogLevel::Info); 
  Logger::getInstance().print("Red: ", LogLevel::Info); Logger::getInstance().print(CS.Red, LogLevel::Info); Logger::getInstance().println("\n", LogLevel::Info); 

  Logger::getInstance().println("TSL2591 data", LogLevel::Info);
  Logger::getInstance().print("Visible: ", LogLevel::Info); Logger::getInstance().print(TSL_DAT.visible, LogLevel::Info); Logger::getInstance().println(" lux", LogLevel::Info); 
  Logger::getInstance().print("IR: ", LogLevel::Info); Logger::getInstance().print(TSL_DAT.ir, LogLevel::Info); Logger::getInstance().println(" lux", LogLevel::Info); 
  Logger::getInstance().print("Full: ", LogLevel::Info); Logger::getInstance().print(TSL_DAT.full, LogLevel::Info); Logger::getInstance().println(" lux\n", LogLevel::Info); 
  
  Logger::getInstance().println("SCD30 data", LogLevel::Info);
  Logger::getInstance().print("CO2: ", LogLevel::Info); Logger::getInstance().print(SCD30_D.CO2, LogLevel::Info); Logger::getInstance().println("ppm", LogLevel::Info); 
  Logger::getInstance().print("Temperature: ", LogLevel::Info); Logger::getInstance().print(SCD30_D.Temperature, LogLevel::Info); Logger::getInstance().println("C", LogLevel::Info); 
  Logger::getInstance().print("Humidity: ", LogLevel::Info); Logger::getInstance().print(SCD30_D.Humidity, LogLevel::Info); Logger::getInstance().println("RH\n", LogLevel::Info); 
  
  Logger::getInstance().println("MIX8410 data", LogLevel::Info);
  Logger::getInstance().print("O2: ", LogLevel::Info); Logger::getInstance().print(O2val, LogLevel::Info); Logger::getInstance().println("\n", LogLevel::Info); 
  
  Logger::getInstance().println("MAX4466", LogLevel::Info);
  Logger::getInstance().print("Audio: ", LogLevel::Info); Logger::getInstance().print(audio, LogLevel::Info); Logger::getInstance().println("\n", LogLevel::Info); 
  
  
  
	// MQTT UPDATE
	M_Client.sendData(attribute_names[CONN],  "Connected");
	M_Client.sendData(attribute_names[MAX4466_Audio], String(audio).c_str());
	M_Client.sendData(attribute_names[MIX8410_O2], String(O2val).c_str());

	M_Client.sendData(attribute_names[SCD30_CO2],String(SCD30_D.CO2).c_str());
	M_Client.sendData(attribute_names[SCD30_hum],   String(SCD30_D.Humidity).c_str());
	M_Client.sendData(attribute_names[SCD30_temp],  String(SCD30_D.Temperature).c_str());

	M_Client.sendData(attribute_names[ambimate_Voc],String(A_DAT.voc_ppm).c_str());
  M_Client.sendData(attribute_names[ambimate_hum],String(A_DAT.Humidity).c_str());
  M_Client.sendData(attribute_names[ambimate_temp],String(A_DAT.temperatureC).c_str());
  M_Client.sendData(attribute_names[ambimate_Eco2],String(A_DAT.eco2_ppm).c_str());
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
